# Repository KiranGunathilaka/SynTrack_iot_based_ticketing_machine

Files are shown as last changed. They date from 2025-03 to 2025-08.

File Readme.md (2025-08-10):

# Syntrack System

[Proposal](Readme_assets/Syntech-IoT_proposal.pdf)

[1st presentation](Readme_assets/First_Presentation.pdf)

[2nd presentation](Readme_assets/2nd_Presentation.pdf)

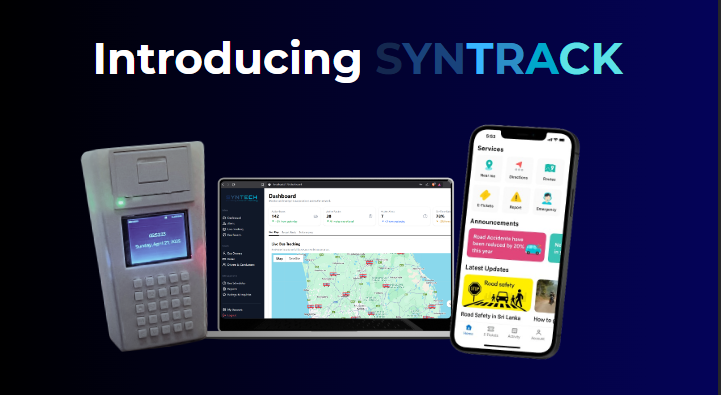
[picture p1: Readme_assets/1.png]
System

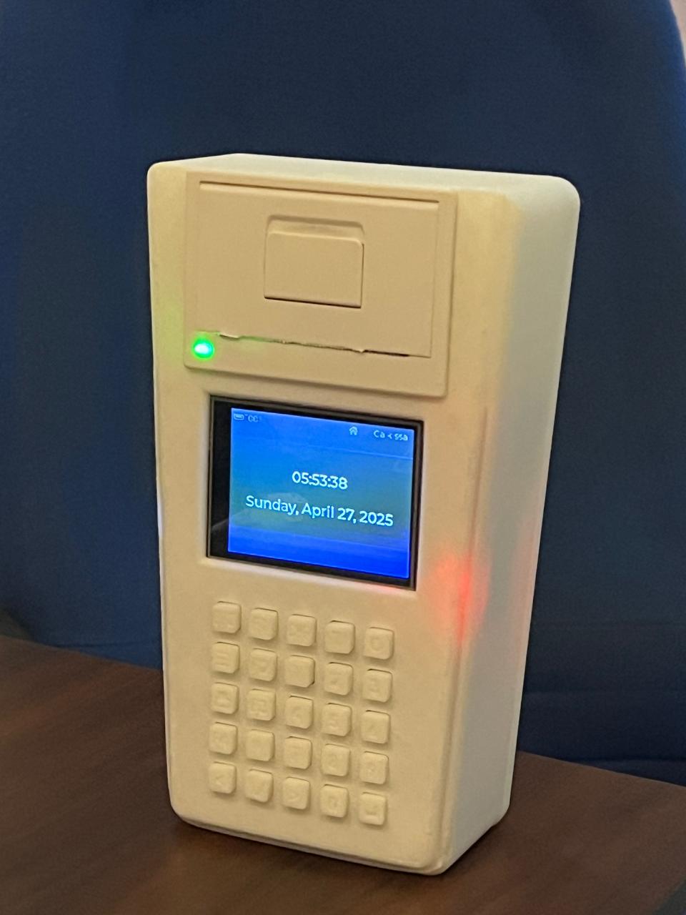
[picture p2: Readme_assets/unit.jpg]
Device

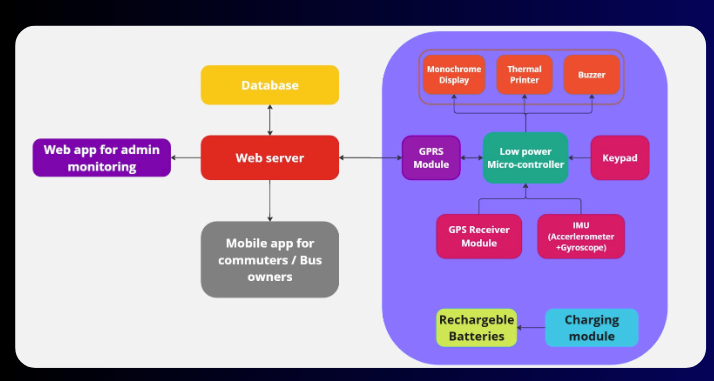
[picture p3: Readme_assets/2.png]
Brief Diagram

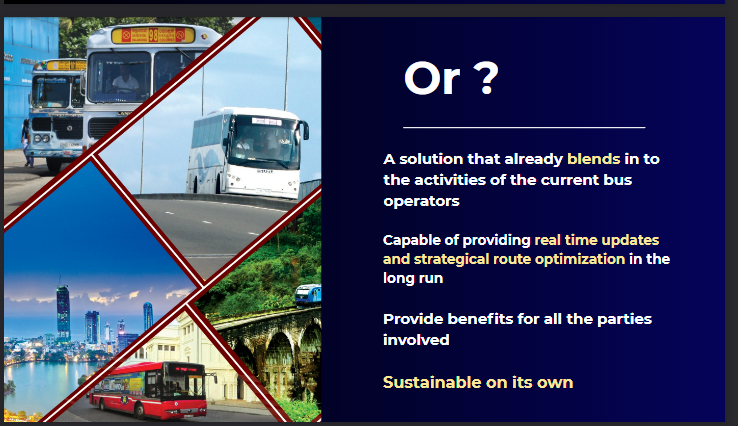
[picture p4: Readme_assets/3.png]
Why?


Enclosure V1
Enclosure V2

<div style="font-family: system-ui, -apple-system, Segoe UI, Roboto, Arial, sans-serif; line-height:1.4;">
  <h2 style="margin:0 0 8px;">Schematic Design</h2>
  <div style="display:grid; grid-template-columns:repeat(auto-fit, minmax(220px,1fr)); gap:12px; margin-bottom:20px;">
    <a href="https://res.cloudinary.com/dxavadkl2/image/upload/v1754797902/Job1_page-0001_mwngek.jpg" target="_blank" rel="noopener">
      Schematic Design — Page 1
    </a>
    <a href="https://res.cloudinary.com/dxavadkl2/image/upload/v1754797902/Job1_page-0002_kv0zv4.jpg" target="_blank" rel="noopener">
      Schematic Design — Page 2
    </a>
    <a href="https://res.cloudinary.com/dxavadkl2/image/upload/v1754797902/Job1_page-0003_uoopd7.jpg" target="_blank" rel="noopener">
      Schematic Design — Page 3
    </a>
    <a href="https://res.cloudinary.com/dxavadkl2/image/upload/v1754797902/Job1_page-0004_pi1ovk.jpg" target="_blank" rel="noopener">
      Schematic Design — Page 4
    </a>
    <a href="https://res.cloudinary.com/dxavadkl2/image/upload/v1754797902/Job1_page-0005_osse2e.jpg" target="_blank" rel="noopener">
      Schematic Design — Page 5
    </a>
    <a href="https://res.cloudinary.com/dxavadkl2/image/upload/v1754797902/Job1_page-0006_uicuav.jpg" target="_blank" rel="noopener">
      Schematic Design — Page 6
    </a>
    <a href="https://res.cloudinary.com/dxavadkl2/image/upload/v1754797901/Job1_page-0007_g4s4ae.jpg" target="_blank" rel="noopener">
      Schematic Design — Page 7
    </a>
    <a href="https://res.cloudinary.com/dxavadkl2/image/upload/v1754797901/Job1_page-0008_mnyr2u.jpg" target="_blank" rel="noopener">
      Schematic Design — Page 8
    </a>
    <a href="https://res.cloudinary.com/dxavadkl2/image/upload/v1754797901/Job1_page-0009_vxmq06.jpg" target="_blank" rel="noopener">
      Schematic Design — Page 9
    </a>
    <a href="https://res.cloudinary.com/dxavadkl2/image/upload/v1754797901/Job1_page-0010_rjnhxx.jpg" target="_blank" rel="noopener">
      Schematic Design — Page 10
    </a>
    <a href="https://res.cloudinary.com/dxavadkl2/image/upload/v1754797901/Job1_page-0011_hrwrx5.jpg" target="_blank" rel="noopener">
      Schematic Design — Page 11
    </a>
  </div>

  <h2 style="margin:0 0 8px;">PCB 2D (Routing)</h2>
  <div style="display:grid; grid-template-columns:repeat(auto-fit, minmax(220px,1fr)); gap:12px; margin-bottom:20px;">
    <a href="https://res.cloudinary.com/dxavadkl2/image/upload/v1754686981/Screenshot_2025-08-09_013852_g663fi.png" target="_blank" rel="noopener">
      PCB 2D Routing — View 1
    </a>
    <a href="https://res.cloudinary.com/dxavadkl2/image/upload/v1754686981/Screenshot_2025-08-09_013907_rphc70.png" target="_blank" rel="noopener">
      PCB 2D Routing — View 2
    </a>
    <a href="https://res.cloudinary.com/dxavadkl2/image/upload/v1754686980/Screenshot_2025-08-09_013914_csmo0g.png" target="_blank" rel="noopener">
      PCB 2D Routing — View 3
    </a>
    <a href="https://res.cloudinary.com/dxavadkl2/image/upload/v1754686980/Screenshot_2025-08-09_013922_lapydj.png" target="_blank" rel="noopener">
      PCB 2D Routing — View 4
    </a>
  </div>

  <h2 style="margin:0 0 8px;">3D View</h2>
  <div style="display:grid; grid-template-columns:repeat(auto-fit, minmax(220px,1fr)); gap:12px; margin-bottom:20px;">
    <a href="https://res.cloudinary.com/dxavadkl2/image/upload/v1754686980/Screenshot_2025-08-09_014124_jlmipr.png" target="_blank" rel="noopener">
      3D View — Image 1
    </a>
    <a href="https://res.cloudinary.com/dxavadkl2/image/upload/v1754686980/Screenshot_2025-08-09_014212_eycq3m.png" target="_blank" rel="noopener">
      3D View — Image 2
    </a>
  </div>

  <div style="margin-top:10px; padding:12px; background:#f9fafb; border:1px solid #eee; border-radius:8px;">
    <p style="margin:0 0 6px;"><strong>Notes</strong></p>
    <ul style="margin:0 0 0 18px;">
      <li>All layers are ground-poured except the layer above the bottom layer, which is the 3.3&nbsp;V plane.</li>
      <li>Design isn’t fully complete. Midway through, due to time and budget constraints, the PCB was deprioritized. Placement and routing aren’t fully optimized; this was completed as a learning exercise to make use of the time already invested.</li>
    </ul>
  </div>
</div>

[Some collabarative files are here too](https://github.com/KavishkaJayakody/SLIoT_Syntec)

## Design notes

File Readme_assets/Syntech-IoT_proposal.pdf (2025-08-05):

# IoT-enabled Bus Ticketing Device Project Proposal

Team Name | Syntech-IoT
Category | University Category

# 1) Problem Definition

## 1.1) Introduction

Sri Lanka’s public bus system is essential for daily commutes but faces persistent challenges such as overcrowding, unreliable schedules, financial mismanagement, and safety concerns. These issues result in commuter discomfort, wasted time, and financial losses for bus operators. The primary cause is the lack of real-time information on bus occupancy, location, and arrival times, forcing operators to rely on inefficient fixed schedules due to limited data on ridership patterns.

Additionally, poor compliance with speed limits and route adherence compromises safety and reliability, often going unchecked due to inadequate monitoring.

To address these challenges, our team proposes an IoT-enabled ticketing machine that not only streamlines ticketing but also collects real-time operational data. Since ticketing machines are already a mandatory requirement in the public transport sector, integrating IoT functionality into them is a more efficient and cost-effective approach than deploying a separate monitoring system.

This solution will benefit commuters, operators, bus owners, and regulators by improving efficiency, comfort, safety, and decision-making. Moreover, while existing ticketing machines are priced above Rs. 35,000, our product offers these advanced features at a significantly lower cost, making it an affordable and effective solution for transport management and network monitoring.

## 1.2) Problem Analysis

It is very evident that the Sri Lanka’s public bus system have become inefficient and unreliable according to public opinion and first-hand experiences, leading to several challenges:
- Time Wastage: Unreliable schedules force passengers to wait long periods without knowing when a bus will arrive.

- Inefficient Route Mapping: Uneven bus distribution causes overcrowding on some routes and underutilization on others.
- Limited Night-time Service: Few buses operate at night, leaving passengers stranded.
- Lack of Accountability: No mechanism exists for passengers to report misconduct or poor service.
- Unsafe Rides: Reckless driving and poor safety enforcement create hazardous travel conditions.
- Route Uncertainty: No reliable system exists to guide commuters, tourists on the best routes to their destination, bus stops for the routes in non-urban areas.
- Cash Payment Issues: Dependence on cash leads to overpaying or difficulties in finding exact change and there’s no transparency between the operators, owners and the authorities.
- Environmental Impact: Paper tickets contribute to litter and waste; an e-ticketing system can reduce this burden.

Our solution wishes to address each of this issues by utilizing our IoT device and its software counterpart.

# 2)Proposed Solution

## 2.1) Proposed Product

IoT-enabled Ticket Issuing Machine with mobile transit app
Our device enhances Sri Lanka's public bus network by tracking real-time data and improving efficiency.
Key Features:
- Tracks bus location, occupancy, and speed in real-time.
- Transmits data to a central system for analysis and optimization.
- Display the route data and collect feedback through a mobile application.

Breakdown
1. Real-Time Data Tracking
- Location Tracking: GPS provides live bus locations via ticket issuing machine.
- Speed Monitoring: Detects speeding; sends alerts for safety.
- Route Adherence: Ensures compliance with predefined routes.
2. Ticket Issuing with IoT Integration
- Passenger Count: Monitors number of tickets issued.
- Occupancy Monitoring: Prevents overcrowding with real-time capacity updates.
- Payment Options: Supports cash, contactless, and digital payments.

3. Centralized System & Analysis
- Collects and securely transmits data (location, speed, occupancy).
- Uses AI/ML to identify patterns for route optimization and demand management.
4. Stakeholder Benefits
- Commuters: Access live bus updates via an app to reduce waiting times.
- Operators: Optimize scheduling and identify inefficiencies.
- Authorities: Enforce safety, improve planning, and manage routes better.
5. Notifications and Alerts
- Commuters: Get updates on arrivals, seat availability, and delays.
- Operators/Regulators : Receive alerts for overcrowding, speeding, and route deviations.
6. Future Scalability
- Expansion: Begin with pilot routes and scale to the full network.
- Integration: Potential to connect with smart city systems and traffic management.

## 2.2) Uniqueness of the Solution

1. Upgrade to Existing System
Enhances traditional handheld ticketing machines simplifying adoption by leveraging familiar tools, making implementation easier compared to entirely new systems.
2. Real-Time Speed and Safety Monitoring
Combines GPS and speed tracking to detect reckless driving, proactively ensuring passenger safety and addressing Sri Lanka’s road conditions.
3. Passenger Feedback System
Empowers passengers to report issues or commend service, promoting accountability and service improvements beyond just operational metrics.
4. Overloading Control with Ticket Monitoring
Integrates passenger limits and pre-booking to manage passenger capacity, directly addressing overloading and improving boarding efficiency.
5. Real-Time Bus Tracking for Passengers
Provides live bus locations and arrival times, a first for Sri Lanka's private and SLTB buses, enhancing trip planning, reliability, and convenience.
6. Data-Driven Insights
Collects actionable data for route optimization, road safety and policy planning, supporting both operational efficiency and long-term infrastructure improvements.

# 3)Technical Overview and Implementation

## 3.1) Technical Details

The | IoT-enabled
ticketing machine will be
employing a low-power micro-controller as it needs to operate for a maximum duration using battery power. It will utilize a keypad to take inputs from the conductor and outputs will be delivered to the monochrome LCD display, thermal printer and a buzzer as a usual
ticketing | machine. | Crowd

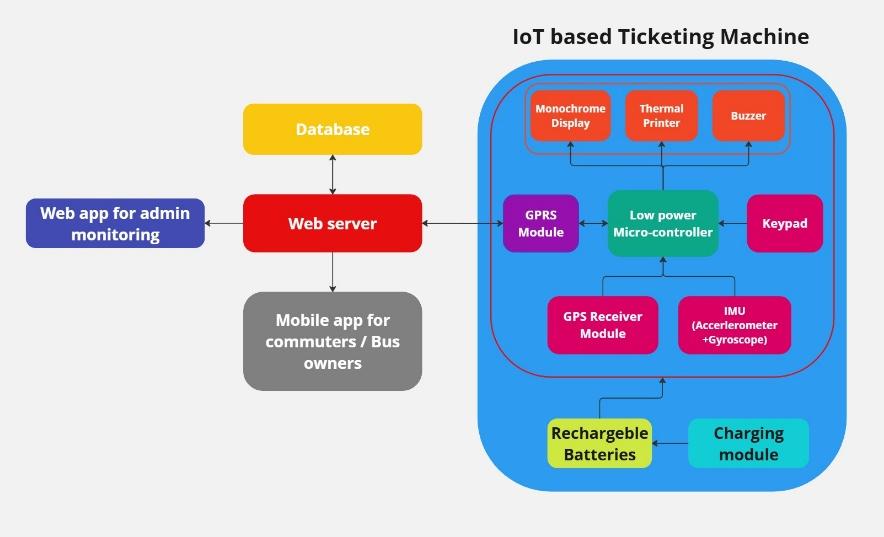
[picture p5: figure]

information will be recorded and reported to the server by tracking the issued tickets count and start and destination of the issued tickets. The GPRS (General Packet Radio Service) module will allow the device to access cellular networks using a SIM card thus enabling HTTP/IP communication between the webserver and device. The GPS receiver module will capture location/ velocity and time data from the GPS/GNSS networks, and captured data will be continuously delivered to the webserver. This data will be processed and displayed on the commuter mobile app and admin web app so that end users can see next arriving bus, estimated times, number of busses in the route, occupancy of the bus, and other additional features. Also drivers and conductors will able to see the number of waiting commuters through the device as the server and IoT device communication is bi-directional. The IMU sensor will be used to detect rapid acceleration/decelerations and that data will be processed along with location data real-time, in the server or on-device, using a pre-trained ML model, to identify irregular, unsafe driving patterns and crash incidents.

## 3.2) User Scenario

For conductors, the device will function as a standard ticketing machine, requiring no extra effort. For commuters, the app will notify when a bus is ready to depart from the depot, displaying its real-time location and estimated arrival times at stops. This allows users to adjust their schedules and minimize waiting times. Additionally, real-time occupancy data will help commuters decide whether to board the current bus, wait for the next, or take an alternate route. Commuters can also mark themselves as “waiting” for routes with flexible or night schedules. This lets drivers see the number of waiting passengers and adjust their routes slightly to improve convenience and safety.

# Team Details

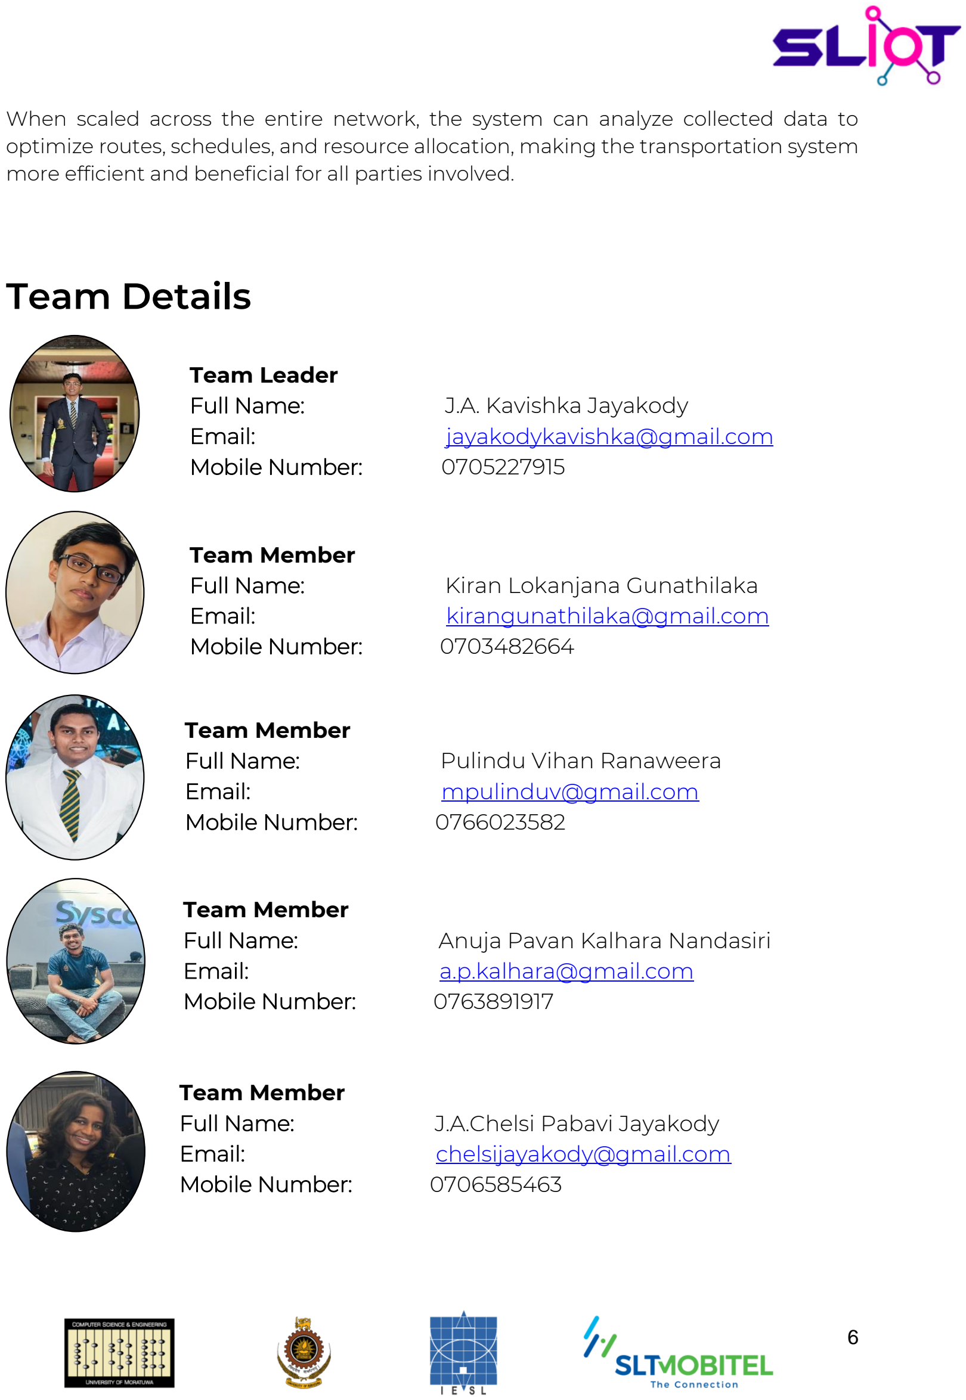
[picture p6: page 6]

When scaled across the entire network, the system can analyze collected data to optimize routes, schedules, and resource allocation, making the transportation system more efficient and beneficial for all parties involved.

Team Leader
Full Name: | J.A. Kavishka Jayakody
Email: | jayakodykavishka@gmail.com
Mobile Number: | 0705227915

Team Member
Full Name: | Kiran Lokanjana Gunathilaka
Email: | kirangunathilaka@gmail.com
Mobile Number: | 0703482664

Team Member
Full Name: | Anuja Pavan Kalhara Nandasiri
Email: | a.p.kalhara@gmail.com
Mobile Number: | 0763891917

Team Member
Full Name: | Pulindu Vihan Ranaweera
Email: | mpulinduv@gmail.com
Mobile Number: | 0766023582

Team Member
Full Name: | J.A.Chelsi Pabavi Jayakody
Email: | chelsijayakody@gmail.com
Mobile Number: | 0706585463

# 4) Additional Information

For the system to be successfully implemented and deliver its full benefits, it must be deployed across all buses within at least one urban area. Additionally, to ensure the system’s effectiveness, all commuters must be required by law to obtain tickets.

To accommodate all demographics, the e-ticketing system should be introduced alongside traditional paper tickets, as some passengers may lack the technological literacy to adopt digital payments immediately. Furthermore, while e-ticketing is a crucial enhancement, it may not be included in the Minimum Viable Product (MVP) and can be introduced as a future extension based on the system’s success.

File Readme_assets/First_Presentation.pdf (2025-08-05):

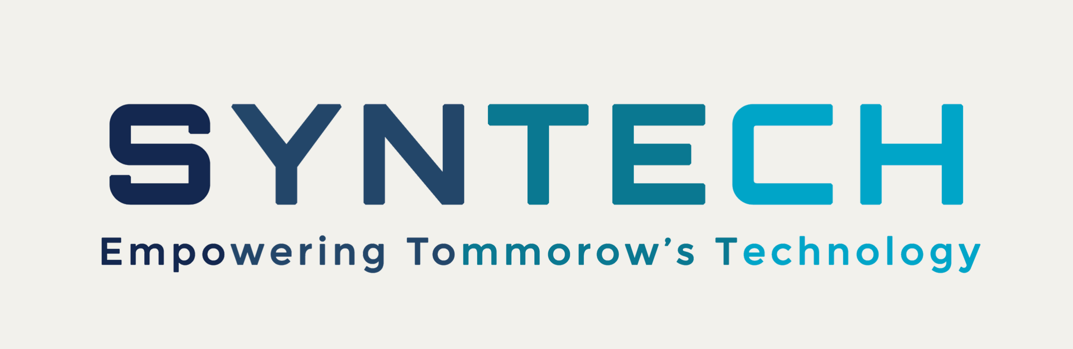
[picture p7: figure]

# Are you satisfied with the current bus transportation?

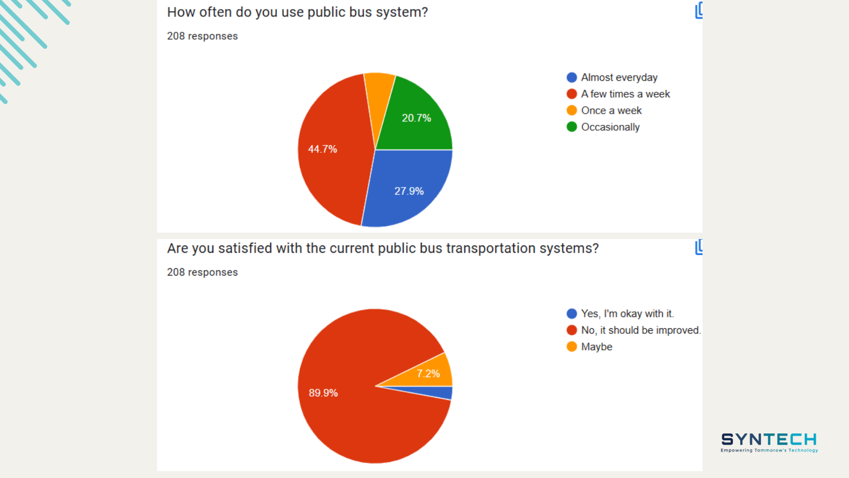
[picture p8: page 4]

# Problem Statement

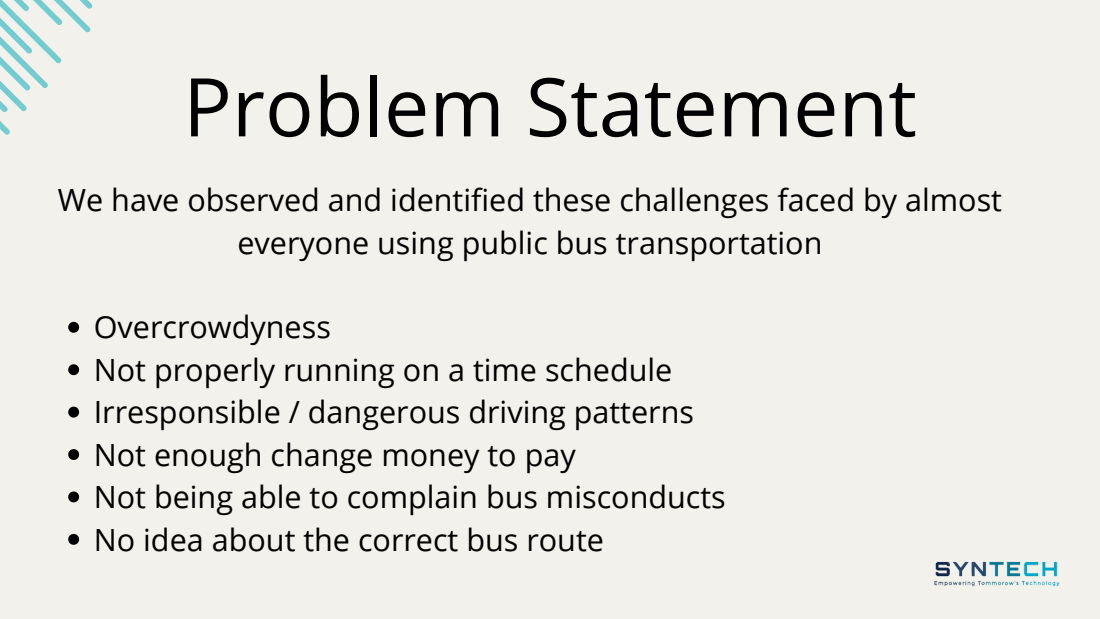
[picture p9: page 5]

We have observed and identified these challenges faced by almost

everyone using public bus transportation

Overcrowdyness
Not properly running on a time schedule
Irresponsible / dangerous driving patterns
Not enough change money to pay
Not being able to complain bus misconducts
No idea about the correct bus route

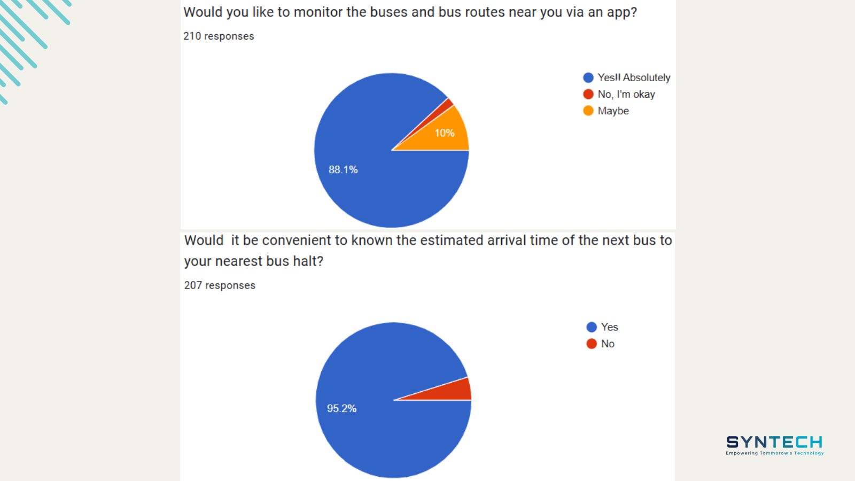
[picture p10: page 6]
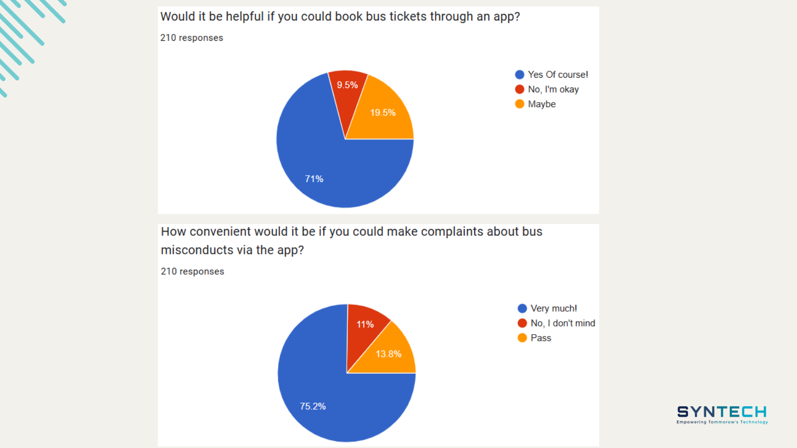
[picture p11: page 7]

# What Can We Do

A fixed GPS tracker attached to the bus. A community based data collection system

To Regulate And Monitor Busses

Intergrate a GPS tracker and a bus data monitoring unit to get insights Using legal officers to monitor busses constantly

# An IoT Enabled Ticketing Machine

A ticketing machine similar to the existing bus ticketing machine Intergrated GPS tracker
Real time motion detection Passesnger count feed

# IoT enabled Bus Ticketing Device

# Device Features

Our Device act as a ordinary bus ticketing machine from the bus conductors end but with IoT capabilities

TFT LCD display with 5 x 5 scanning Keyboard

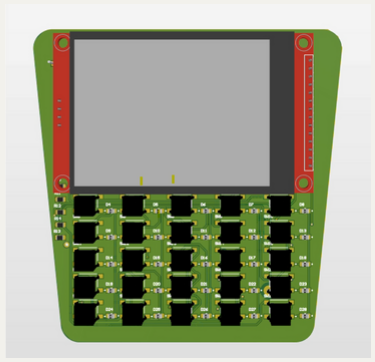
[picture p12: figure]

58mm Thermal Printer

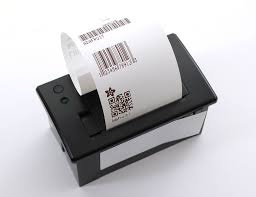
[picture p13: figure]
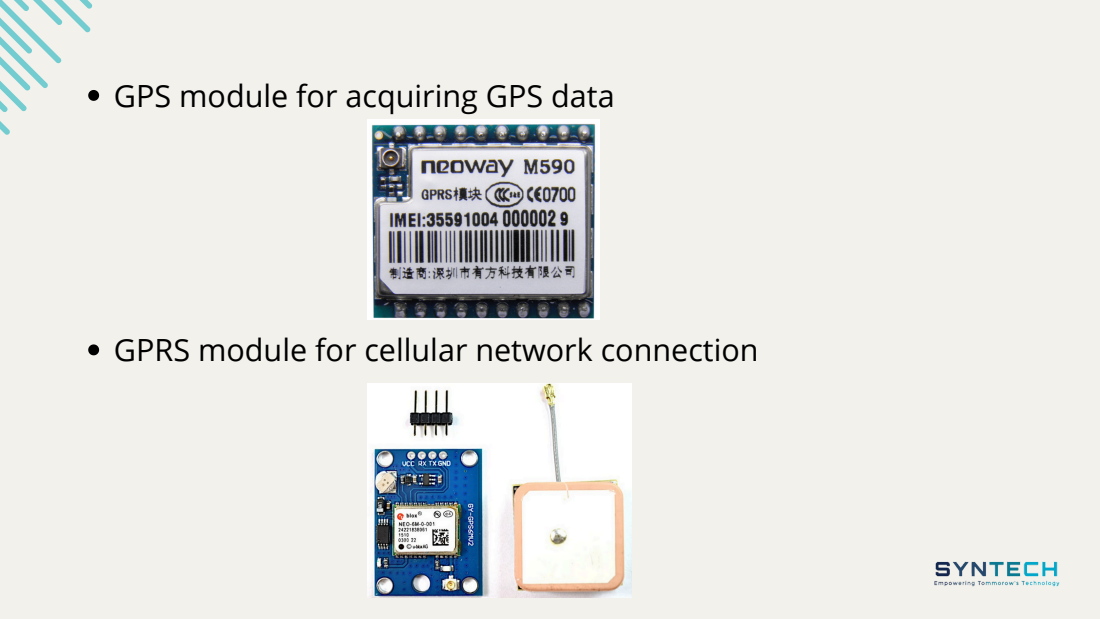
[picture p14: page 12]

GPS module for acquiring GPS data

GPRS module for cellular network connection

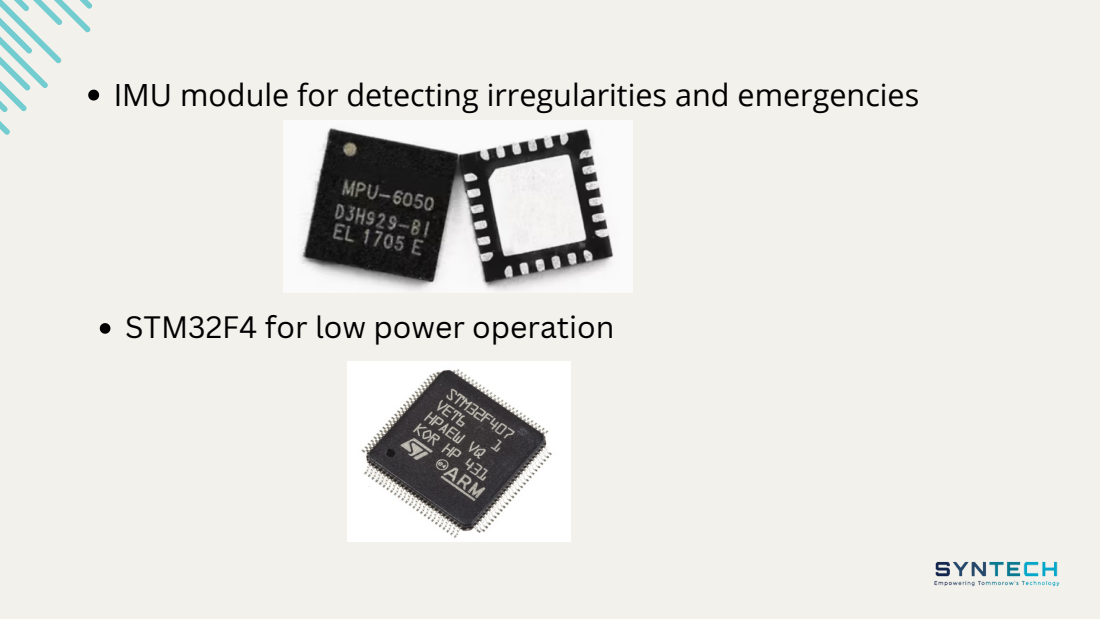
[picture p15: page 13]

IMU module for detecting irregularities and emergencies

STM32F4 for low power operation

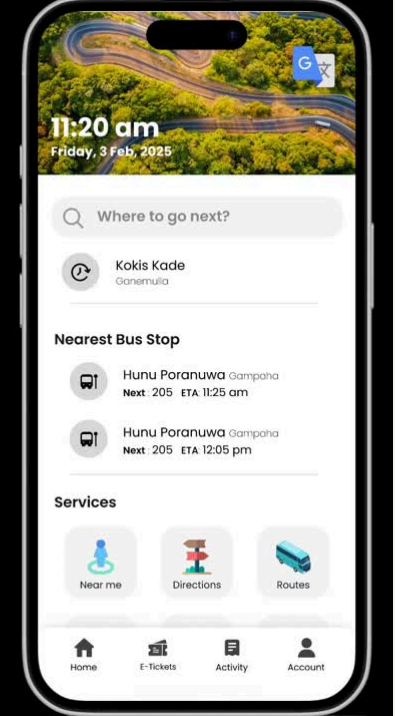
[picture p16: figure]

# SYNTRACK

## Commuter App

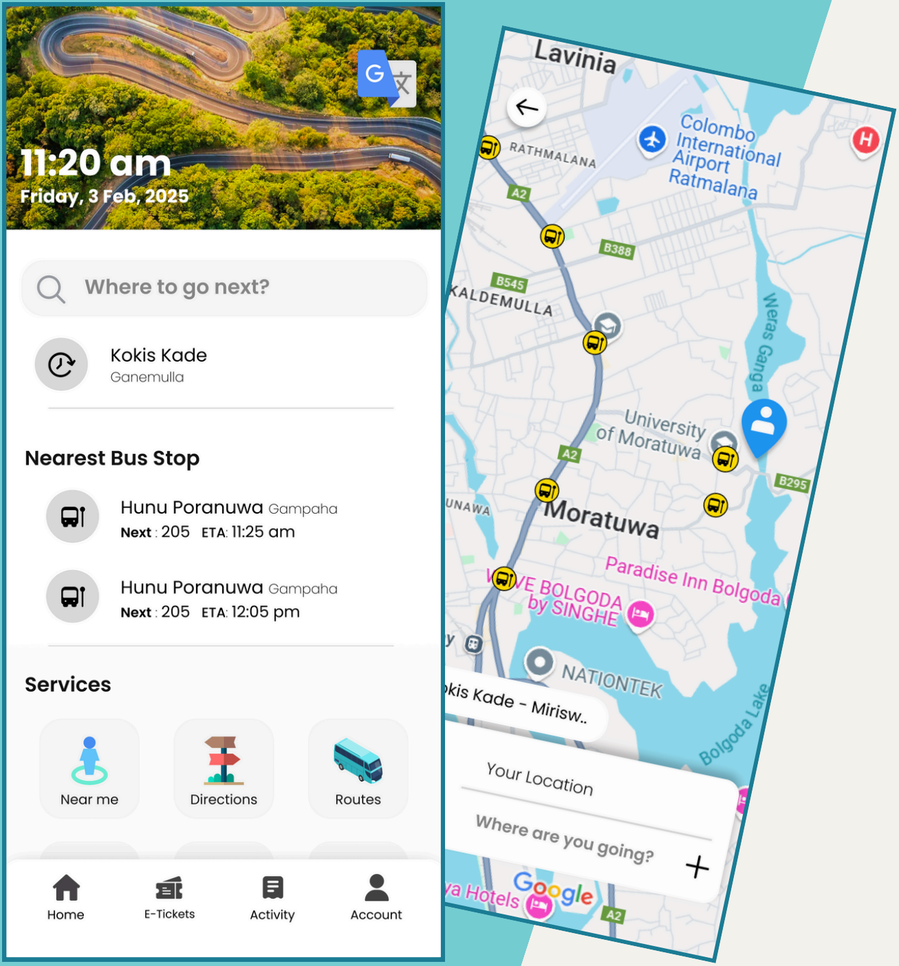
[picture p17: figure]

# DESIGN

Familiar Designs
Accessibility

## IMPLEMENTATION

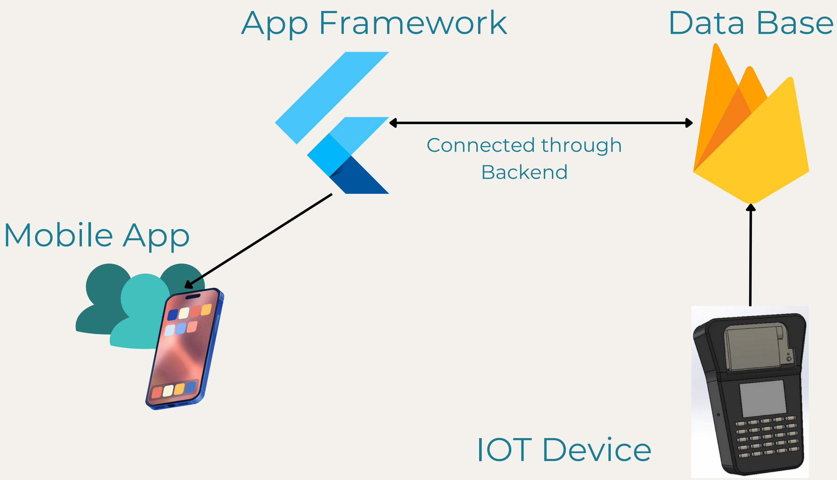
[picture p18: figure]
App Framework; Data Base; IOT Device; Mobile App; Connected through Backend

## Real Time Bus Tracking

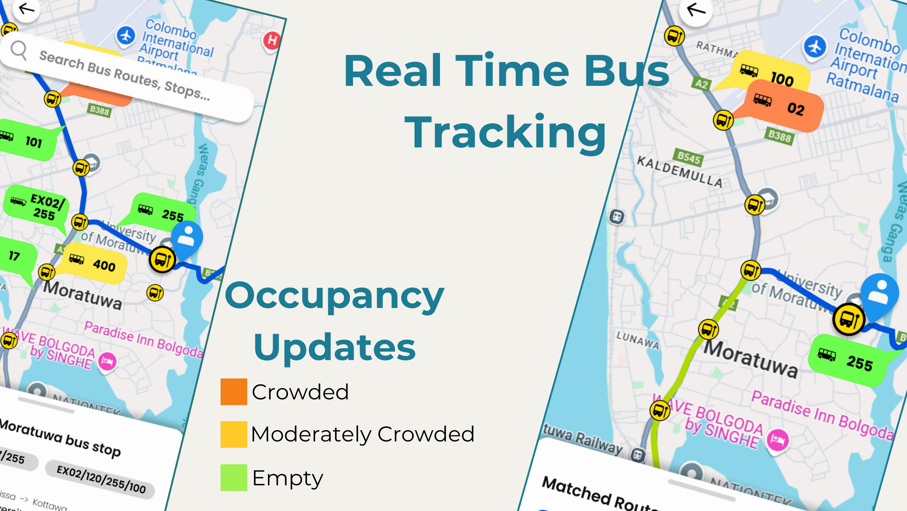
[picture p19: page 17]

## Occupancy Updates

Crowded
Moderately Crowded
Empty

## Commuter Support

## Route Info

Ticketing | Notifications

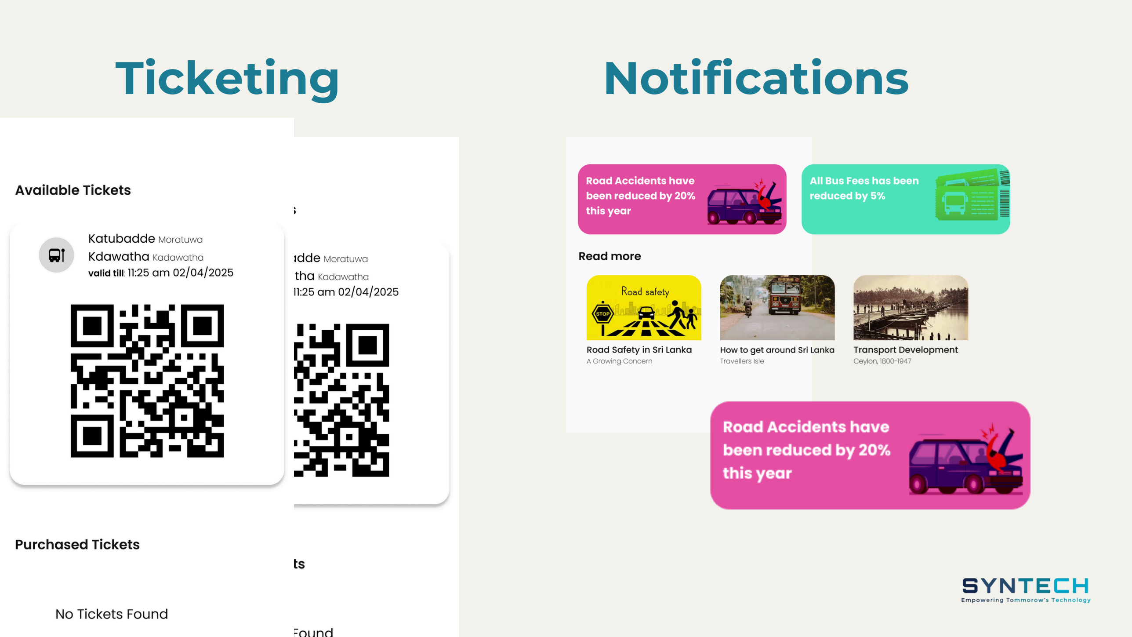
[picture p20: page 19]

# SYNTRACK

## Commuter App

Smoother Safer Predictable

# Web Platform

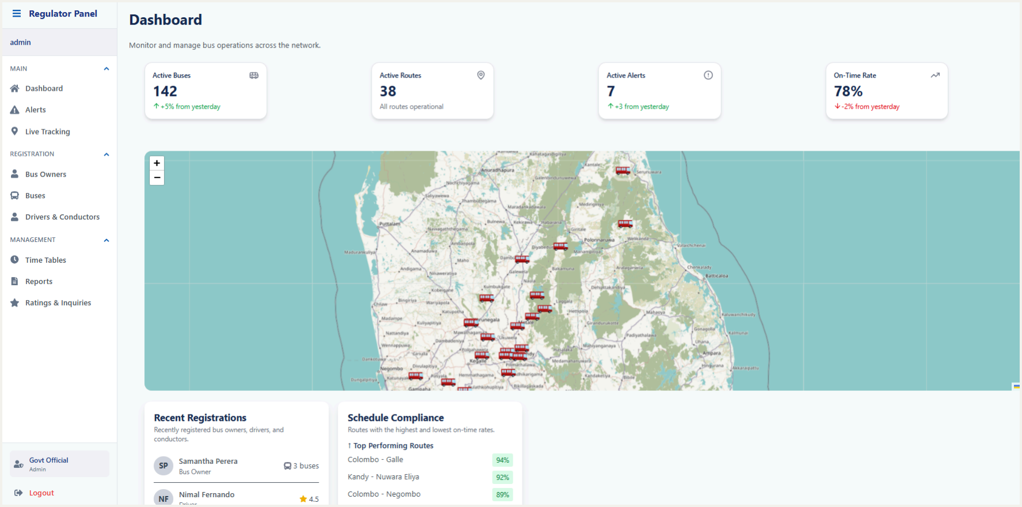
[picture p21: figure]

# Web Platform

## Live-tracking of all the busses in the network

## Bus owner and operator registration

## Automated alerts for irresponsible and dangerous driving behavior

## Quarterly report generation featuring optimized resource allocation recommendations based on analyzed

commuter pattern data.

# Future Development

## Adaptive resource allocation for routes using collected commuter patterns

## Aiming for smart city concepts that aligns with Sustainable Development Goals (SDG 17)

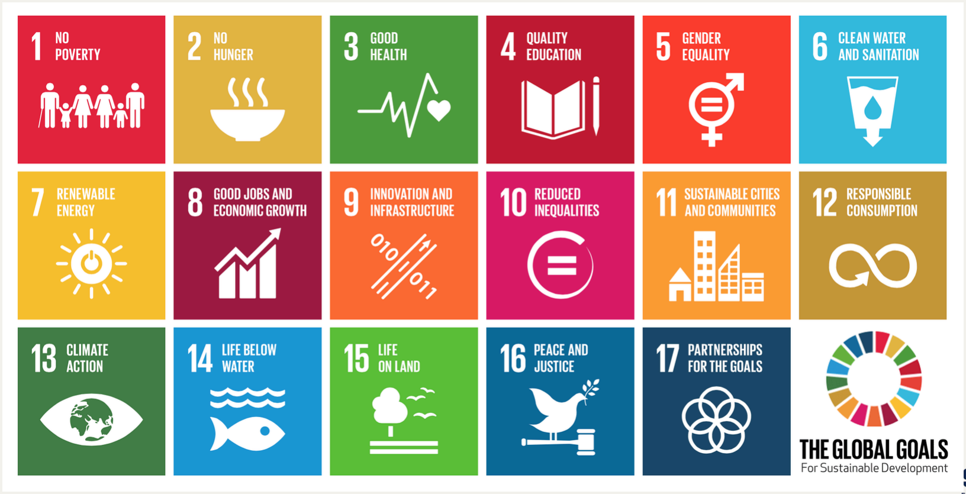
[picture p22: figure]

## Integrate multiple transportation modes and collaborate with service providers to

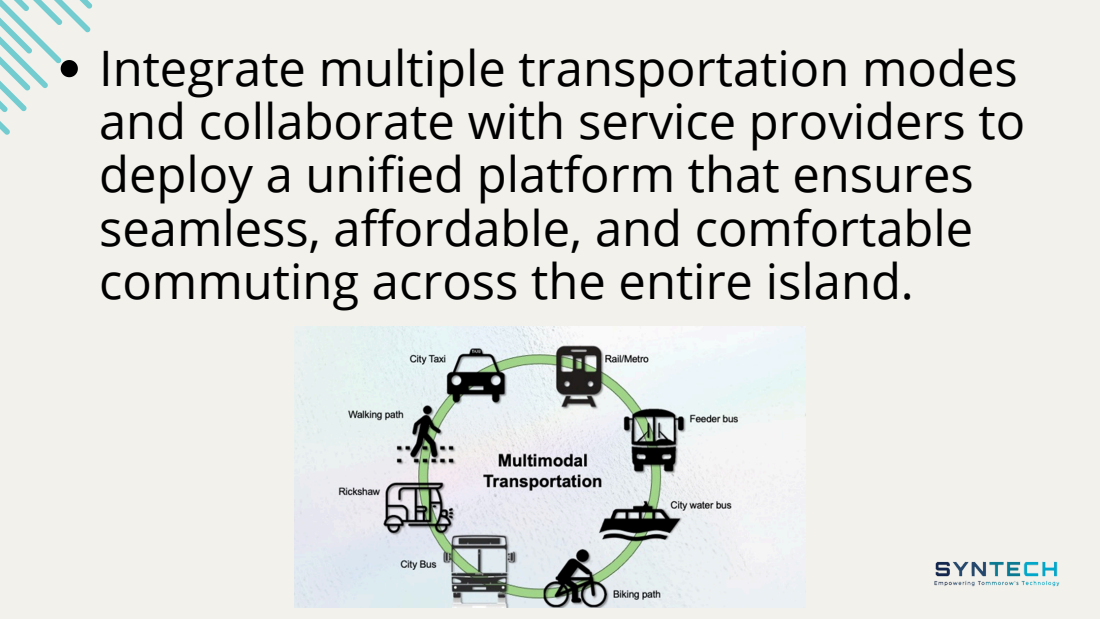
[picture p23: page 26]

deploy a unified platform that ensures
seamless, affordable, and comfortable
commuting across the entire island.

# Our progress

### Ticketing device

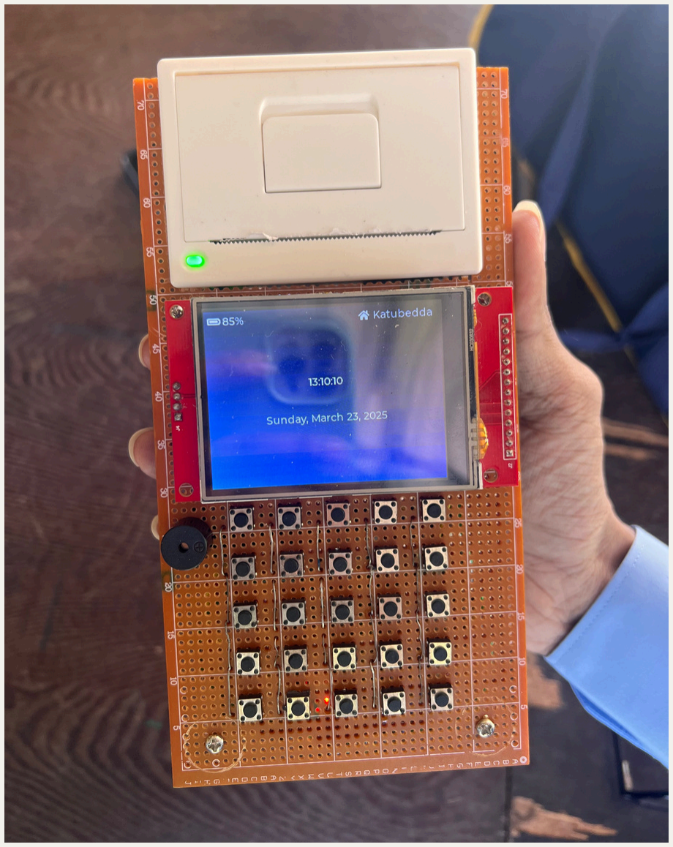
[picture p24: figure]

### Commuter app

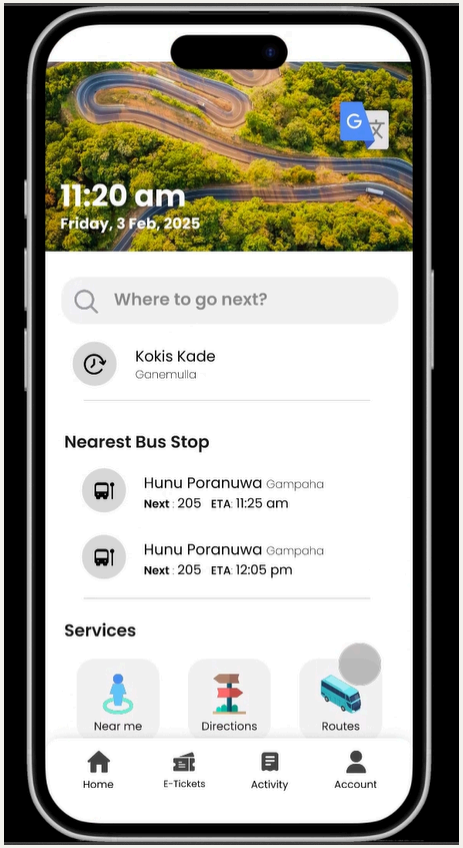
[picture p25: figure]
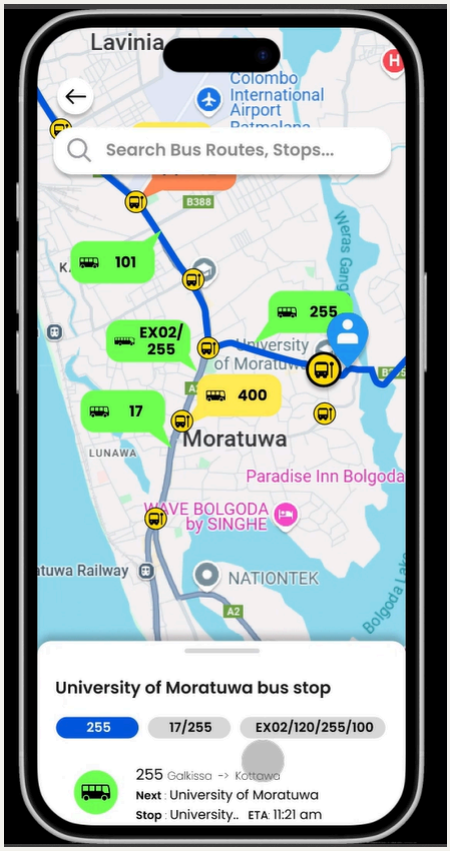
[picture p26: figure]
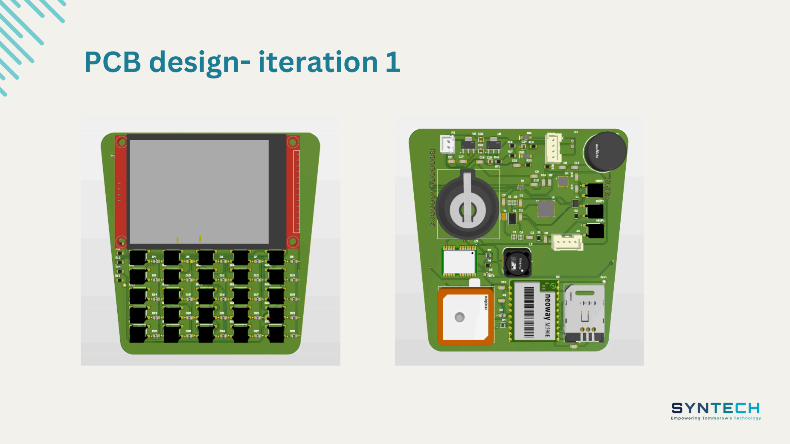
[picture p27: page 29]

### PCB design- iteration 1

### Web portal

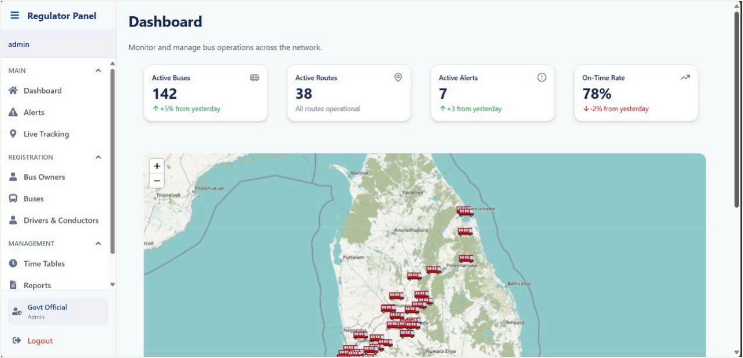
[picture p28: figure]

# Why This System Can Succeed

# Strengths, Challenges & Opportunities

Strengths 40%; Opportunities 30%; Weaknesses 20%; Threats 10%

# Demand & Feasibility


Over 60% of public transport users struggle with inefficiency & fraud.

Ministry of Transport, Highways, Ports and Civil Aviation

GPS tracking is a must → Countries like India, Singapore, and the UK have already implemented similar systems.
Sri Lanka has over 70% smartphone penetration

Expanding 4G & 5G networks
Sri Lanka’s push for digital transformation & smart city projects supports this initiative.

## Business Plan & Revenue Model

Government doesn’t need to keep funding this. It’s self sustaining.

Digital Ticketing Fees → A small service fee per ticket . Advertising Revenue → Sell ad space on bus stops, ticketing machines, and the app.
Data Monetization → Transport analytics for private companies

No. Buses

Time period

Additional

Phase 1 | Phase 2 | Phase 3

## How We Make This Happen

500 buses in Colombo | Scale to 3,000+ intercity buses. | Island - Wide Execution
First 6 months | 6 - 18 months | 18+ Months

Passenger app + real-time tracking system goes live.
Introduce AI-driven route
optimization.

International partnerships &
licensing opportunities.

## How We Mitigate Risks

Resistance from Private Bus Owners ? - Bring new rules and regulations
High Initial Costs? - Staggered investment plan + revenue generation starts early.
Passenger Adoption? - Public awareness campaigns + incentives for digital payments.

# Thank You!

# We are

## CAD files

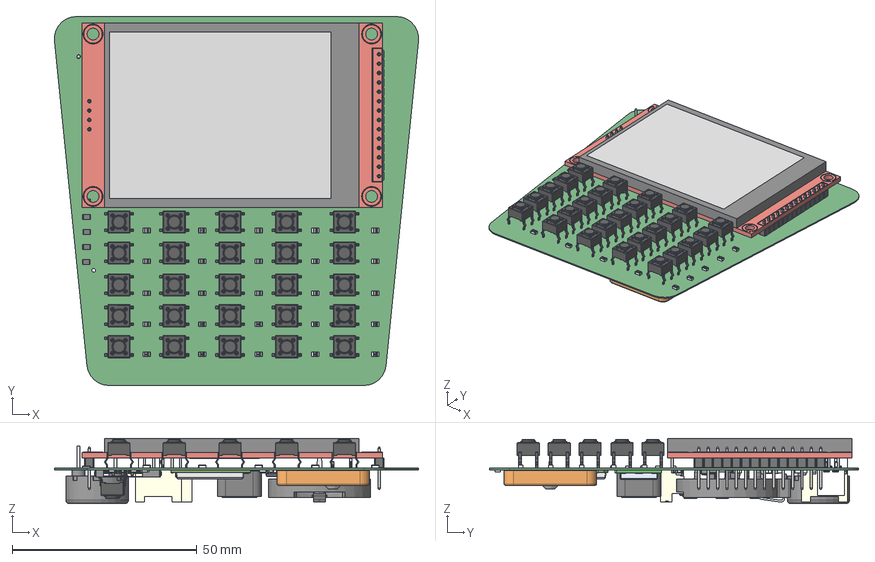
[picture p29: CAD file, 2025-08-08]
PCBs/SynTrack/Main.step
98.7 x 100.0 x 17.7 mm
plastic x 2
pins x 4
terminal
top x 3
logo x 6
Package
Leads
LID
Logo
Switch_C&K_PTS645SM43SMTR92LFS_eec x 28
Notch 2 x 2
Extruded x 67
M590 Neoway
Mid_Body x 14
Mark x 14
part number x 2
terminals x 5
base
Leadframe x 2
Core
ShieldRing
Glue
Vishay logo
1x1_Pin_Header_2.54mm x 18
Molex
notch
Diode_Taiwan_Semiconductor_TS4148_RYG_eec x 162
Cap_KEMET_C0805C472J3HAC_eec x 12
Keystone_Logo
Molex Logo

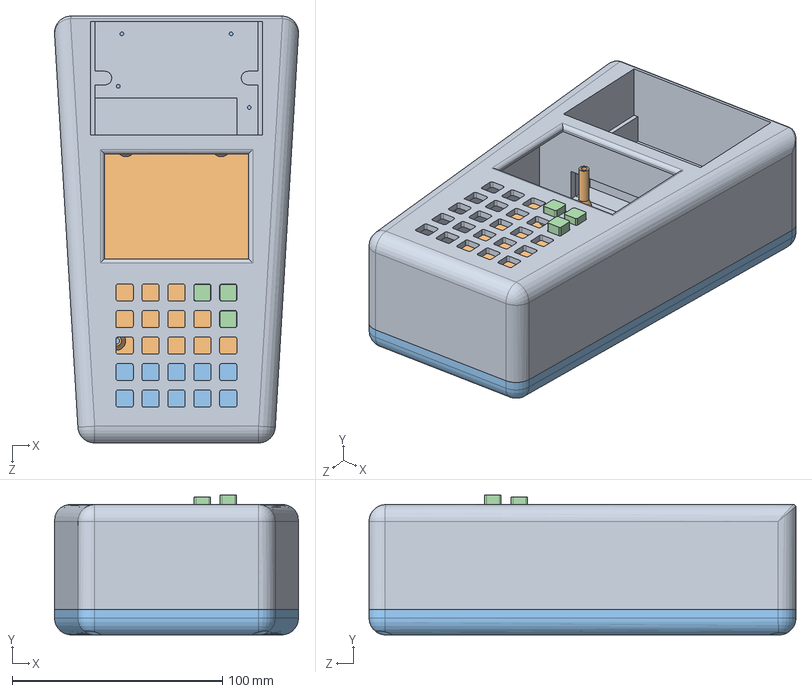
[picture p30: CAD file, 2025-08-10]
Enclosure/Enclosure2/Enclosure/Assem1.SLDASM
116.0 x 66.5 x 203.0 mm
enclsoure2
MidSurface
BackCover
Button x 3

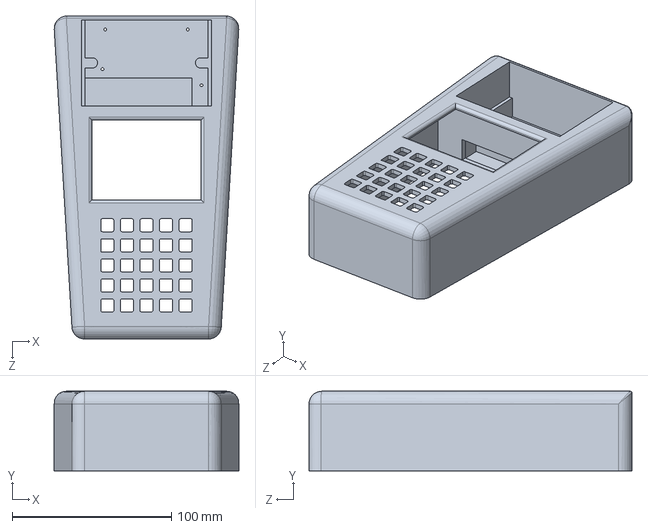
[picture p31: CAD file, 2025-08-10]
Enclosure/Enclosure2/Enclosure/enclsoure2.SLDPRT
116.0 x 50.0 x 203.0 mm

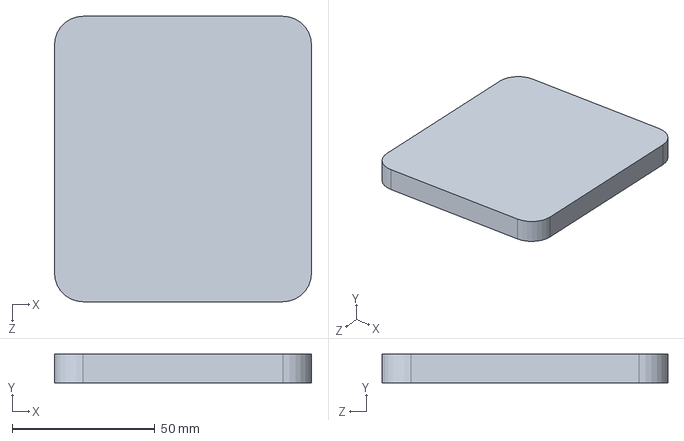
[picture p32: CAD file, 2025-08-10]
Enclosure/Enclosure2/PCB/Part1.SLDPRT
90.0 x 10.0 x 100.0 mm

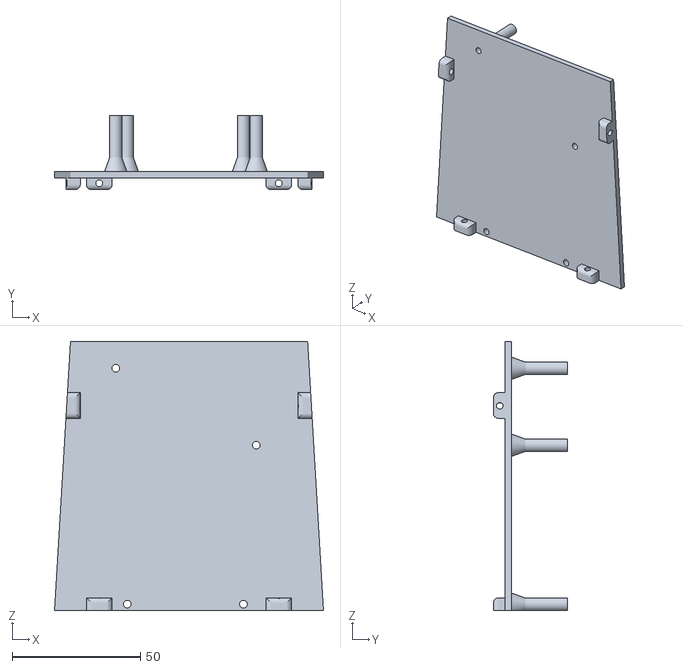
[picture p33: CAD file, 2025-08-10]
Enclosure/Enclosure2/STL/MidSurface.STL
104.9 x 29.0 x 105.0

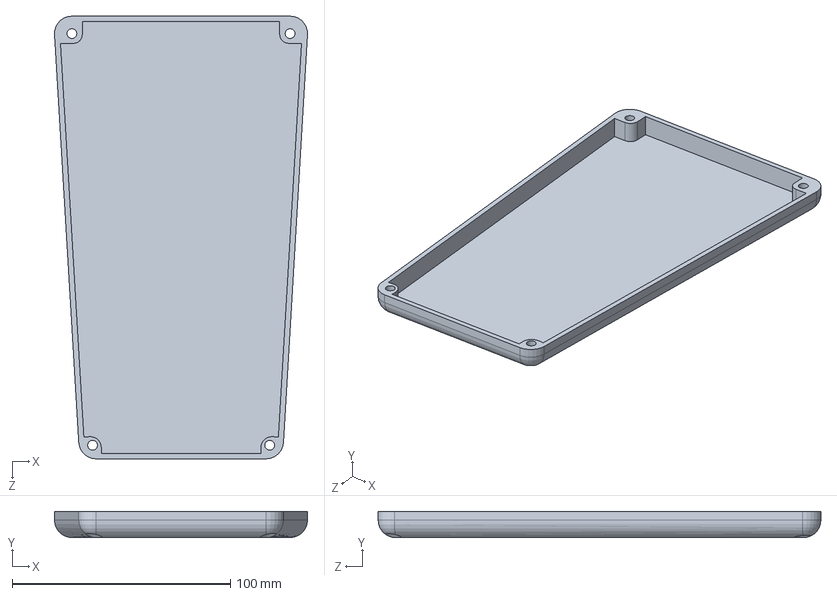
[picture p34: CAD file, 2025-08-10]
Enclosure/Enclosure2/Enclosure/BackCover.SLDPRT
116.0 x 12.0 x 203.0 mm

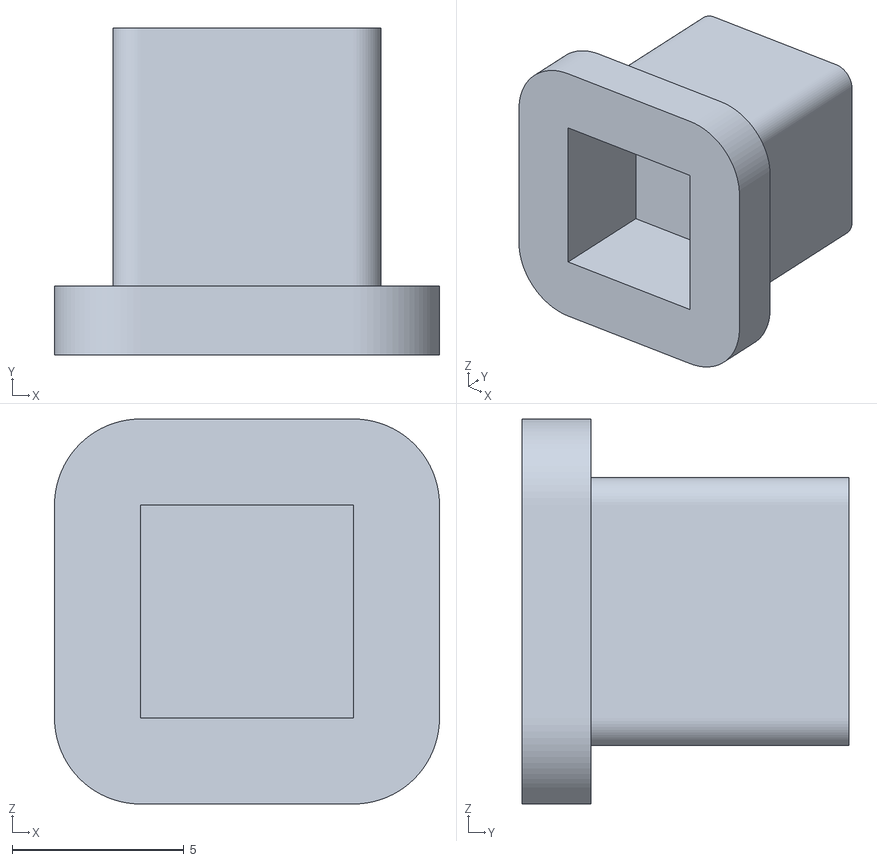
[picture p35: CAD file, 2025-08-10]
Enclosure/Enclosure2/STL/Button.STL
11.2 x 9.50 x 11.2

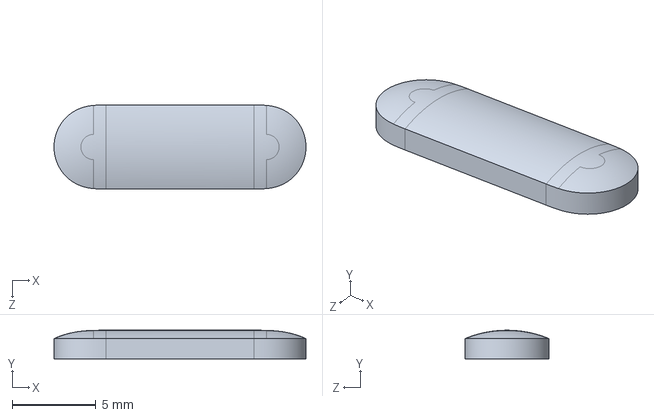
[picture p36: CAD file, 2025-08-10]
Enclosure/Enclosure1/lozengeButton.SLDPRT
15.0 x 1.70 x 5.00 mm

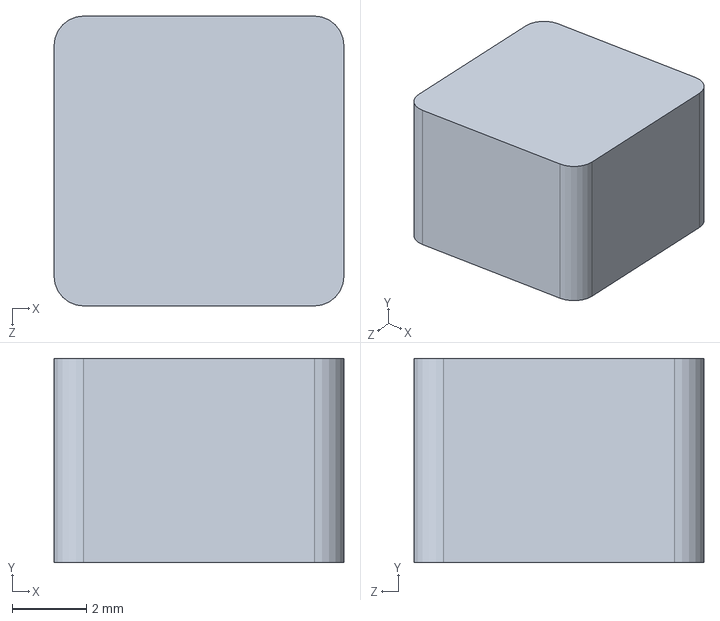
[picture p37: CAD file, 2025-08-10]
Enclosure/Enclosure2/Enclosure/button2.SLDPRT
7.80 x 5.50 x 7.80 mm

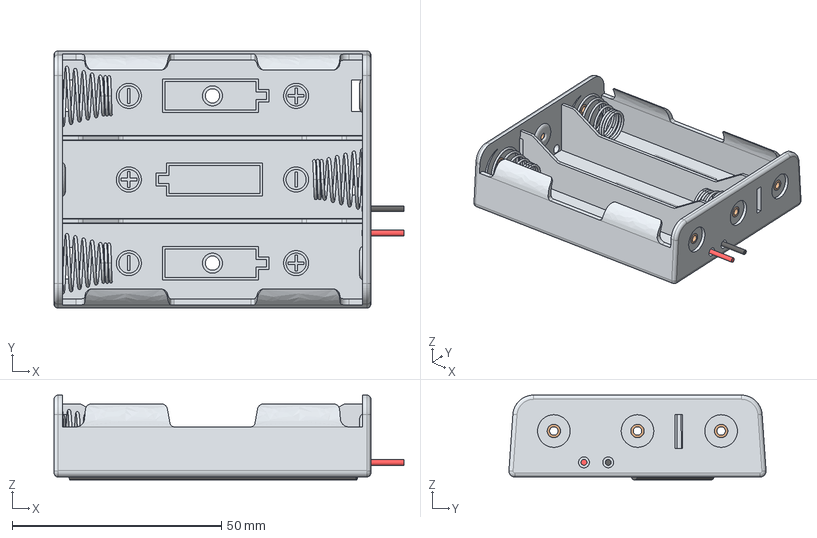
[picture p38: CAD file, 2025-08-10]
Enclosure/Enclosure1/batteryCase18650x3.step
83.7 x 61.5 x 20.3 mm
Corps
FilNoirUnder001
Positif1
Spring1
Spring3
rivet x 6
Positif2
Positif3
FilRouge
FilNoir
FilNoirUnder

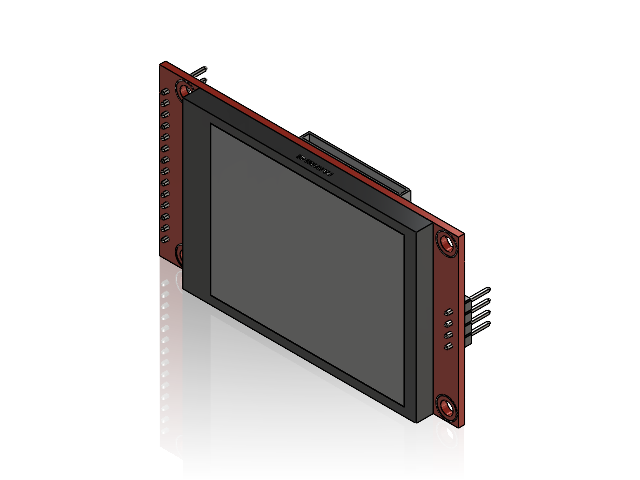
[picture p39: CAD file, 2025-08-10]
Enclosure/Enclosure1/TFT LCD 2.4 inch ILI9341.step.SLDASM
1x1_Pin_Header_2.54mm.step x 4
1x1_Pin_Header_2.54mm_1.step x 14
Component1.step
Component2.step
TFT LCD 2.4 inch ILI9341.step
TFT LCD 2.4 inch ILI9341-0.step
TFT LCD 2.4 inch ILI9341-1.step
TFT LCD 2.4 inch ILI9341-2.step
TFT LCD 2.4 inch ILI9341-3.step
TFT LCD 2.4 inch ILI9341-4.step
TFT LCD 2.4 inch ILI9341-5.step

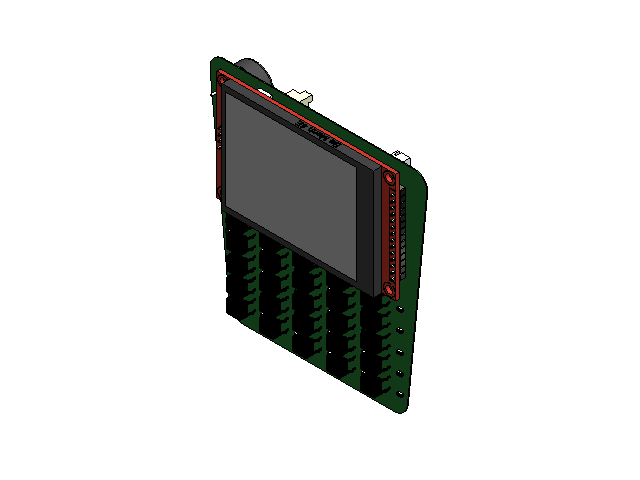
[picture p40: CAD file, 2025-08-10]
Enclosure/Enclosure1/MainPCB.SLDASM
plastic.step x 2
pins.step x 2
body.step
terminal.step
top.step
Logo.step
Package.step
Leads.step
LID.step
Logo_1.step
Switch_C&K_PTS645SM43SMTR92LFS_eec.step x 28
1.step x 2
Notch 2.step x 2
Extruded.step
6324664208.step
M590 Neoway.step
Extruded-0.step
Mid_Body.step x 6
Mark.step x 6
Mid_Body-2.step x 6
Mark-3.step x 6
Extruded-4.step
Extruded-5.step x 2
Extruded-6.step x 3
Extruded-7.step x 6
pins-8.step x 2
body-9.step x 2
top-10.step x 2
part number.step x 2
Mid_Body-12.step
Mark-13.step
Mid_Body-15.step
Mark-16.step
6182227104.step x 2
body-17.step
terminals.step
base.step
logo-18.step
Leadframe.step
Leadframe-19.step
Core.step
ShieldRing.step
Glue.step
1-20.step
2-21.step
3.step
Vishay logo.step
1x1_Pin_Header_2.54mm.step x 14
1x1_Pin_Header_2.54mm-22.step x 4
1-23.step
2-24.step
3-25.step
4.step
5.step
6.step
7.step
Molex.step
notch.step
Extruded-26.step x 2
Extruded-27.step x 2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

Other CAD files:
Enclosure/Enclosure1/14x1_Pin_Header_2.54mm.step.SLDASM
Enclosure/Enclosure1/04x1_Pin_Header_2.54mm.step.SLDASM
Enclosure/Enclosure1/TFT LCD 2.4 inch ILI9341-3.step.SLDPRT
Enclosure/Enclosure2/Enclosure/Button.SLDPRT
Enclosure/Enclosure2/STL/BackCover.STL
Enclosure/Enclosure2/STL/enclsoure2.STL
Enclosure/Enclosure1/1x1_Pin_Header_2.54mm.step.SLDPRT
Enclosure/Enclosure1/1x1_Pin_Header_2.54mm_1.step.SLDPRT
Enclosure/Enclosure1/Assem1.STL
Enclosure/Enclosure1/Bottom.SLDPRT
Enclosure/Enclosure1/CH340E.stp
Enclosure/Enclosure1/Component1.step.SLDPRT
Enclosure/Enclosure1/Component2.step.SLDPRT
Enclosure/Enclosure1/TFT LCD 2.4 inch ILI9341-0.step.SLDPRT
Enclosure/Enclosure1/TFT LCD 2.4 inch ILI9341-1.step.SLDPRT
Enclosure/Enclosure1/TFT LCD 2.4 inch ILI9341-2.step.SLDPRT
Enclosure/Enclosure1/TFT LCD 2.4 inch ILI9341-4.step.SLDPRT
Enclosure/Enclosure1/TFT LCD 2.4 inch ILI9341-5.step.SLDPRT
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

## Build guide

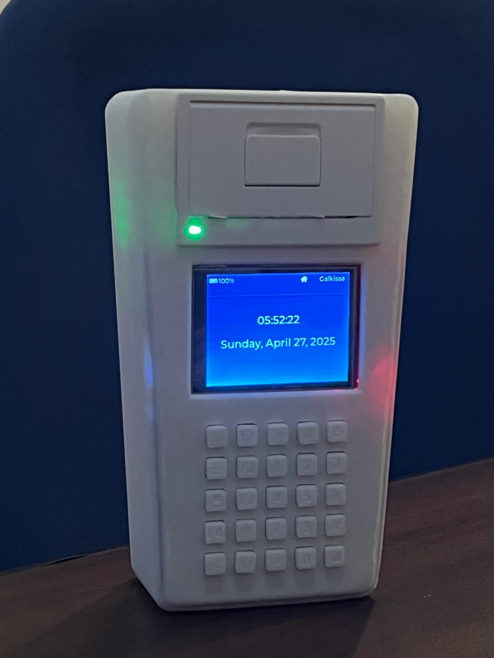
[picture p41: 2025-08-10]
Enclosure/Enclosure2/Enclosure/Printed2.jpg

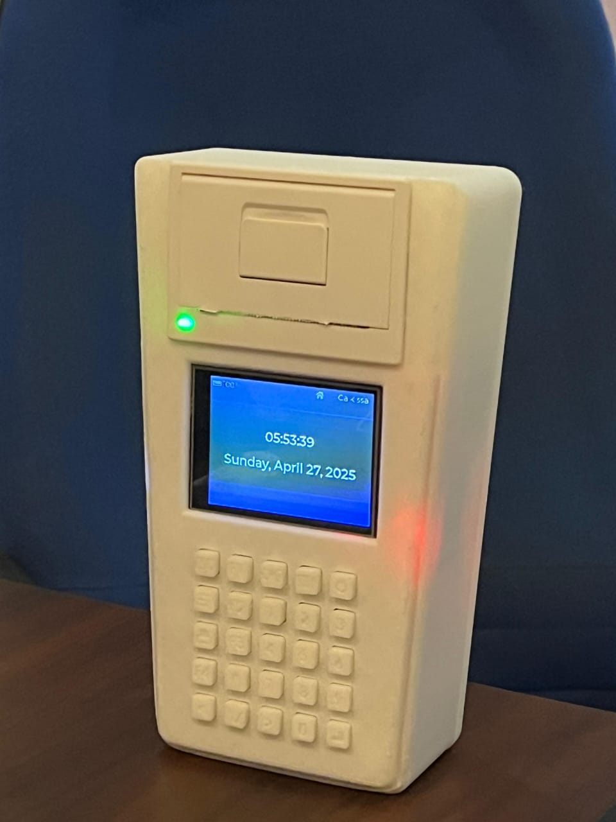
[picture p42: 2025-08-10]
Enclosure/Enclosure2/Enclosure/Printed.jpg

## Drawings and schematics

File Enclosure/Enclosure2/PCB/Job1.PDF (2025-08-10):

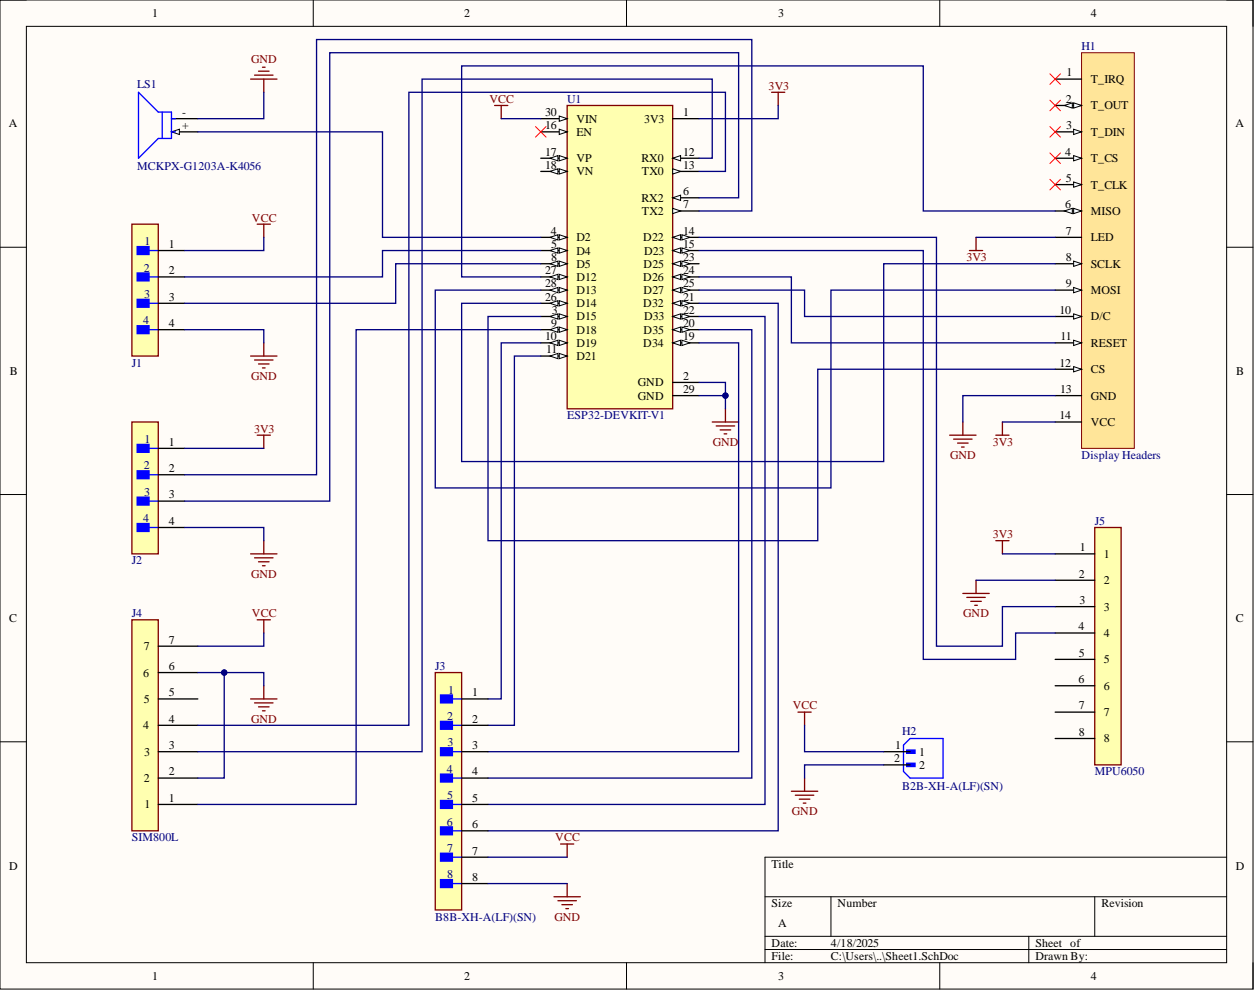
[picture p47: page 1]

VCC U 1

2 7 | | 2 4
2 8 | | 2 5
2 6 | | 2 1 | | | | 1 0
3 | D 1 4 D 3 2 D 1 5 D 3 3 | 2 2
9 | D 1 8 D 3 5 | 2 0 | | | | | | 1 1

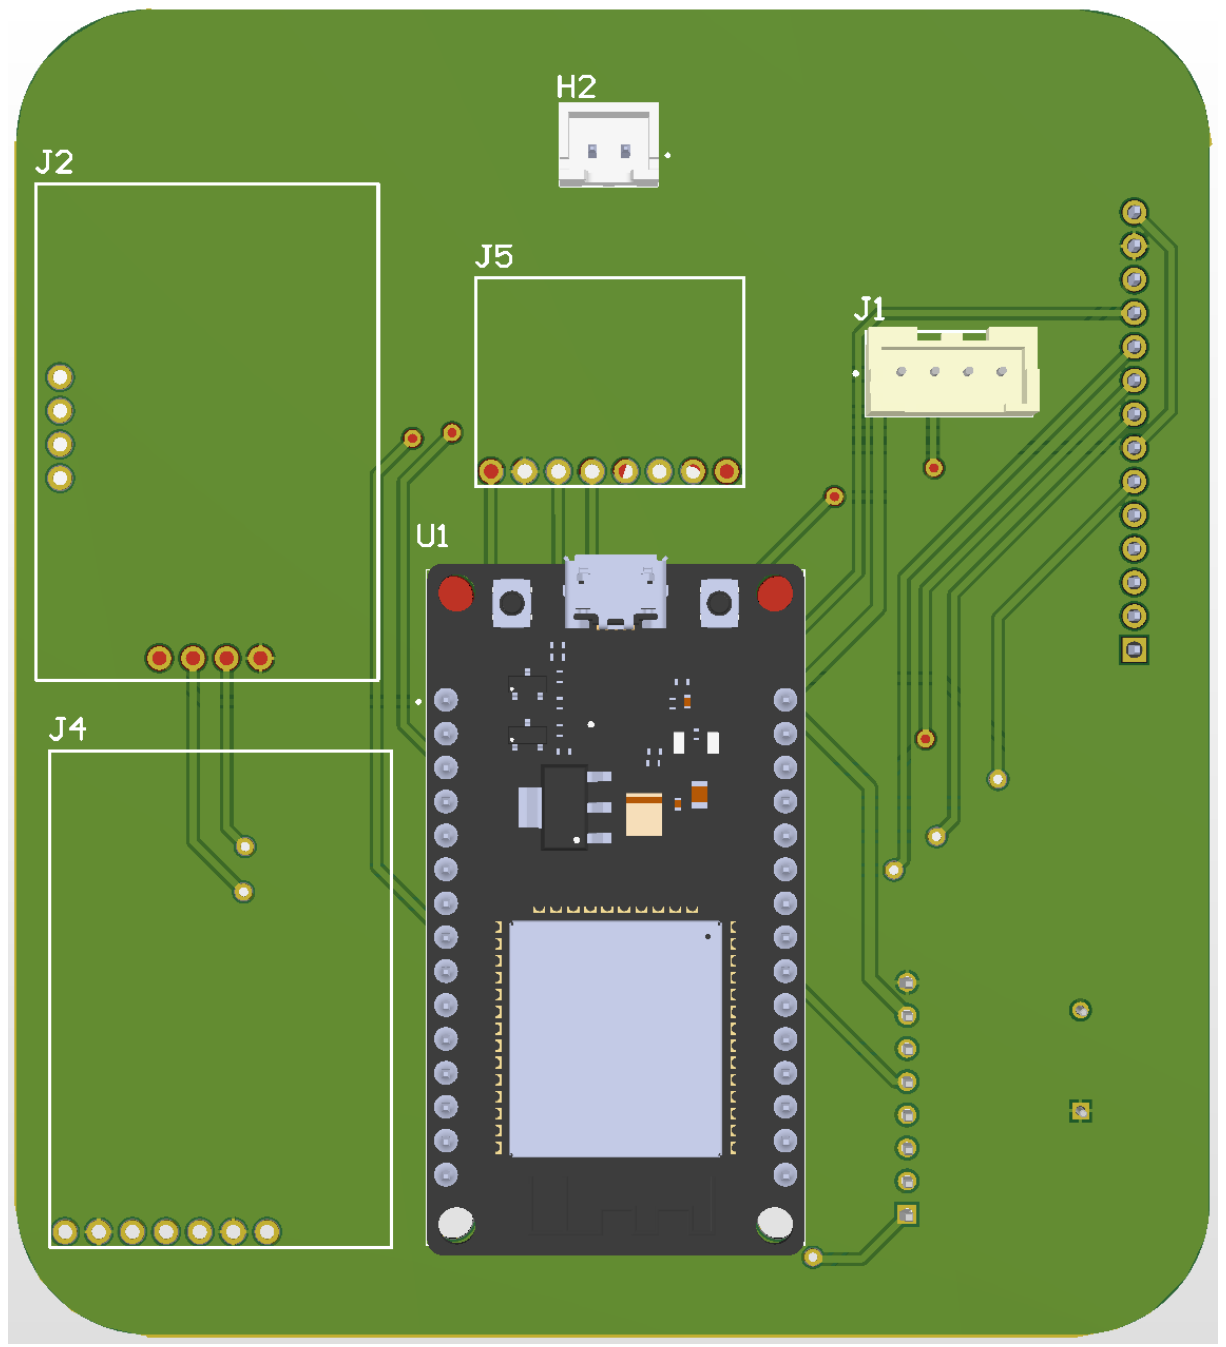
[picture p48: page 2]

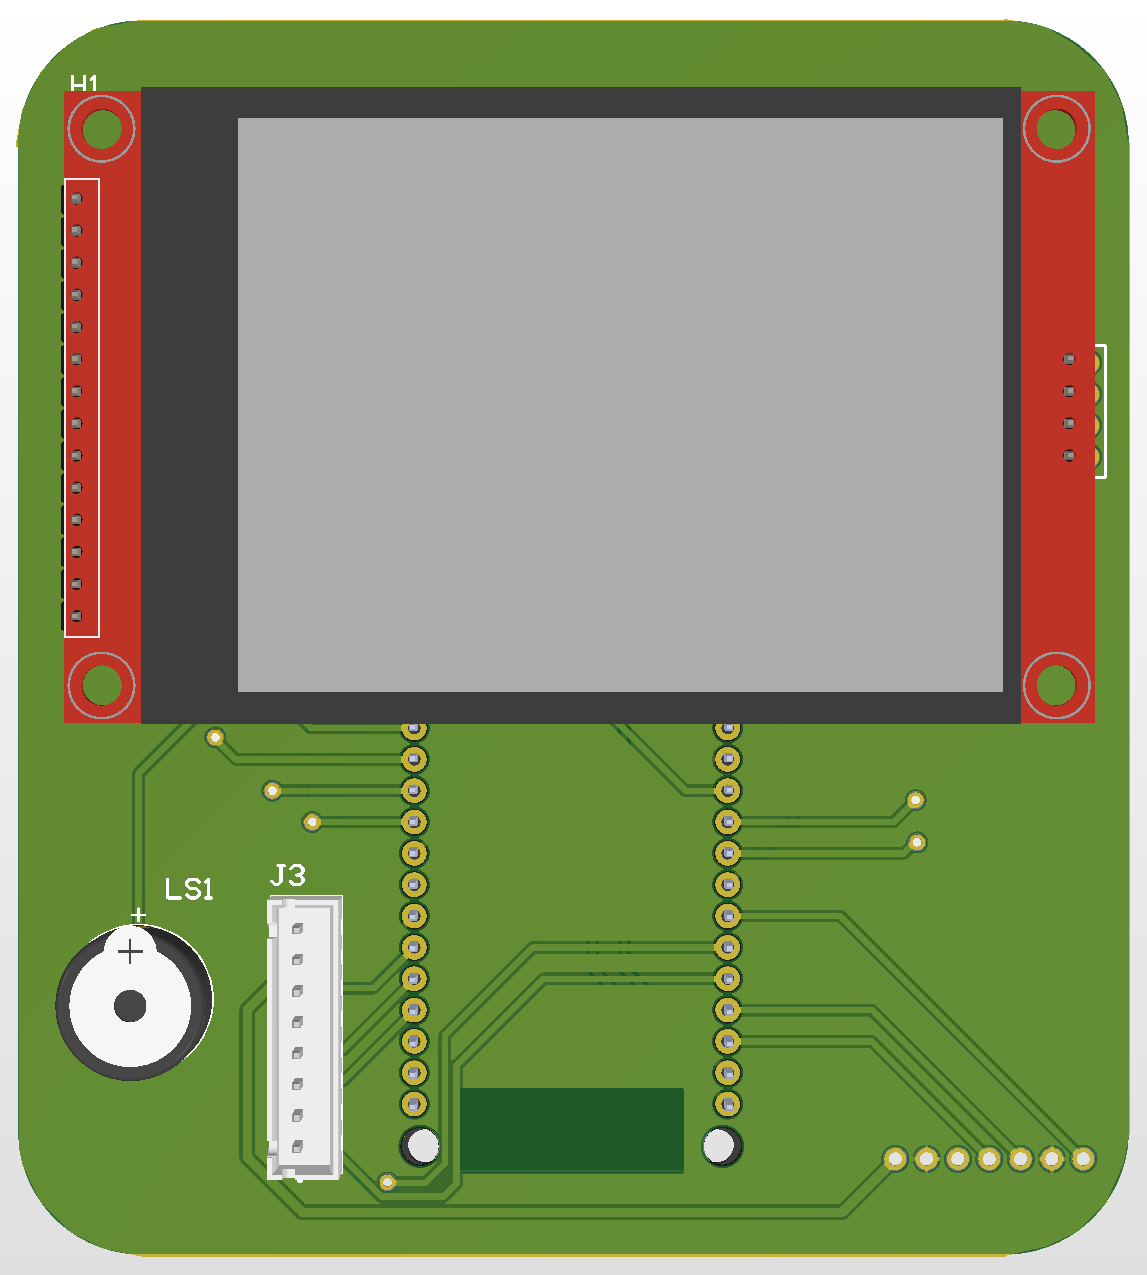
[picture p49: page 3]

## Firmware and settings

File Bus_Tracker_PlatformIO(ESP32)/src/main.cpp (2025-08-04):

#include <Arduino.h>
#include "Config.h"
#include "GPS.h"
#include "Key_Receiver.h"
#include "Bus_Ticket_Printer.h"
#include "Bus_Data.h"
#include "Bus_Display.h"
#include "Firebase_Connector.h"
#include "TimeManager.h"
#include "BusPreferences.h"
#include <Ticker.h>

// Define hardware serial ports
HardwareSerial gpsSerial(GPS_SERIAL_NUM);

// Create instances
GPS gps(&gpsSerial, GPS_RX_PIN, GPS_TX_PIN);
KeyReceiver keyReceiver;
BusTicketPrinter ticketPrinter;
BusDisplay display;
BusData bus;
FirebaseConnector firebase;
TimeManager timeManager;
BusPreferences preferences;


// Ticker objects for timers
Ticker gpsTicker;
Ticker displayTicker;
Ticker timeManagerTicker;

// Firebase timing using millis() instead of ticker
unsigned long previousFirebaseMillis = 0;

// Forward declarations
void updateGPS();
void updateTime();
void updateDisplay();
void sendToFirebase();

void setup() {
    // Initialize debug serial first at high baud rate
    Serial.begin(115200);
    Serial.println("\n\nESP32 Bus System Starting");

    pinMode(BUZZER_PIN, OUTPUT);
  
    tone(BUZZER_PIN, 2000);
    delay(1000);
    noTone(BUZZER_PIN);
  
    
    // Initialize bus preferences first to load saved values
    Serial.println("Initializing preferences...");
    if (preferences.begin()) {
        Serial.println("Preferences initialized successfully");
        // Load saved bus data
        if (preferences.loadBusData(bus)) {
            Serial.println("Loaded saved bus data from preferences");
        } else {
            Serial.println("No saved data found, using defaults");
            
            // Set default bus data if no saved data is found
            bus.registrationNumber = "ND-2314";
            bus.companyName = "Syntech Transit (Pvt) Ltd";
            bus.routeNumber = "0012";
            
            // Get a new reference number or start with default
            bus.referenceNumber = preferences.loadReferenceNumber();
            if (bus.referenceNumber.isEmpty()) {
                bus.referenceNumber = "10000000001";
                preferences.saveReferenceNumber(bus.referenceNumber);
            }
          
            bus.routeName = "Moratuwa - Nittambuwa";
            bus.fromHalt = "Katubedda";
            bus.toHalt = "Kadawatha";
            bus.isFullTicket = true;
            bus.ticketCount = 2;
            bus.unitPrice = 130.00;
          
            bus.driverPhone = "0703482664";
            bus.hotline = "0332297800";
            
            // Save these default values
            preferences.saveBusData(bus);
        }
    } else {
        Serial.println("Preferences initialization failed, using default values");
        
        // Default bus data when preferences fails
        bus.registrationNumber = "ND-2314";
        bus.companyName = "Syntech Transit (Pvt) Ltd";
        bus.routeNumber = "0012";
        bus.referenceNumber = "10000000001";
        
        bus.routeName = "Moratuwa - Nittambuwa";
        bus.fromHalt = "Katubedda";
        bus.toHalt = "Kadawatha";
        bus.isFullTicket = true;
        
        bus.ticketCount = 2;
        bus.unitPrice = 130.00;
        
        bus.driverPhone = "0703482664";
        bus.hotline = "0332297800";
    }
    
    // Set default date and time values that will be updated by TimeManager
    bus.date = "2025/03/21";
    bus.time = "00:00:00";
    
    Serial.println("Initializing display...");
    // Initialize components - start with display
    display.begin();
    delay(100); // Give the display time to initialize
    
    // Initialize time manager
    Serial.println("Initializing TimeManager...");
    if (timeManager.begin()) {
        Serial.println("TimeManager initialized successfully");
        // Update time immediately after successful initialization
        updateTime();
    } else {
        Serial.println("TimeManager initialization failed, using default time");
    }
    
    // Now initialize other components
    keyReceiver.begin();
    ticketPrinter.begin();
    
    // Initialize GPS serial
    Serial.println("Initializing GPS...");
    gpsSerial.begin(GPS_BAUD_RATE, SERIAL_8N1, GPS_RX_PIN, GPS_TX_PIN);
    
    // Initialize Firebase
    Serial.println("Initializing Firebase...");
    if (firebase.begin()) {
        Serial.println("Firebase connection successful");
    } else {
        Serial.println("Firebase connection failed, will retry later");
    }
    
    // Set up display data
    display.setLocation(bus.fromHalt.c_str());
    
    // Set up tickers
    Serial.println("Setting up tickers...");
    displayTicker.attach_ms(20, updateDisplay);  // 200 Hz refresh rate
    gpsTicker.attach(1.0, updateGPS);           // Update GPS every second
    timeManagerTicker.attach(1.0, updateTime);  // Update time every second
    
    // Initialize the previous millis for Firebase timing
    previousFirebaseMillis = millis();

    // Set ticket printer data using the method with BusData and TimeManager
    ticketPrinter.setTicketDataFromBus(bus, timeManager);

    Serial.println("Bus Ticketing System Ready");
}

void updateGPS() {
    gps.update();  // Parse new GPS data
    bus.latitude = gps.getLatitude();
    bus.longitude = gps.getLongitude();
    bus.speed = gps.getSpeedKmh();
}

void updateTime() {
    // Update time manager (checks if NTP sync is needed)
    timeManager.update();
    
    // Get time from TimeManager
    bus.time = timeManager.getTimeString();
    bus.date = timeManager.getDateString();
    
    // Update the time on the display
    display.setTime(
        timeManager.getHour(),
        timeManager.getMinute(),
        timeManager.getSecond()
    );
    
    // Update date on display only if it has changed
    static int lastDay = -1;
    int currentDay = timeManager.getDay();
    
    if (currentDay != lastDay) {
        display.setDate(
            timeManager.getYear(),
            timeManager.getMonth() - 1, // Display expects 0-based month
            timeManager.getDay(),
            timeManager.getDayOfWeek()
        );
        lastDay = currentDay;
    }
}

void updateDisplay() {
    display.update();
    display.setLocation(bus.getCurrentHaltName());
}

// Function to send data to Firebase
void sendToFirebase() {
    // Only send data if Firebase is initialized correctly
    if (firebase.isConnected()) {
        firebase.sendBusData(
            DEVICE_ID,
            bus.latitude,
            bus.longitude,
            bus.speed,
            bus.time,
            bus.getCurrentHaltName(),
            bus.passengerCount,
            bus.getDestinationHaltName()
        );
    } else {
        // Try to reconnect if not connected
        firebase.begin();
    }
}

void loop() {
    // Handle key inputs with the state machine
    keyReceiver.check_Key_and_Execute();
    
    // Check if it's time to send data to Firebase
    unsigned long currentMillis = millis();
    if (currentMillis - previousFirebaseMillis >= FIREBASE_INTERVAL) {
        previousFirebaseMillis = currentMillis;
        sendToFirebase();
    }
}

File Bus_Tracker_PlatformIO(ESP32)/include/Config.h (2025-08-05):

#ifndef CONFIG_H
#define CONFIG_H

// Device Identification
#define DEVICE_ID "bus10001"

// Serial Port Configurations
#define GPS_SERIAL_NUM 2    // UART2
#define PRINTER_SERIAL_NUM 1   // UART1
#define DEBUG_BAUD_RATE 115200
#define GPS_BAUD_RATE 9600
#define GPRS_BAUD_RATE 38400

// GPS Pin Configuration
#define GPS_RX_PIN 16  // Using numeric value instead of GPIO_NUM_16
#define GPS_TX_PIN 17  // Using numeric value instead of GPIO_NUM_17

// GPRS Pin Configuration
#define PRINTER_RX_PIN 5  // Using numeric value instead of GPIO_NUM_5
#define PRINTER_TX_PIN 4  // Using numeric value instead of GPIO_NUM_4

// GPRS Network Configuration
#define GPRS_APN "internet"
#define DEFAULT_SMS_NUMBER "+94712345678"

// TCP Server Configuration
#define TCP_SERVER "your-server.com"
#define TCP_PORT 8080

// Timing Configuration
#define TCP_UPDATE_INTERVAL 60000    // 1 minute in milliseconds
#define GPS_UPDATE_INTERVAL 1000     // 1 second in milliseconds

// Buffer Sizes
#define TCP_MESSAGE_BUFFER_SIZE 256  // Use the larger buffer size

// Screen settings
#define SCREEN_WIDTH 320
#define SCREEN_HEIGHT 240

// WiFi settings
#define WIFI_SSID "Chiki Chiki Bamba"
#define WIFI_PASSWORD "DiscreteFourierTransform"

// Firebase settings

const unsigned long FIREBASE_INTERVAL = 10000; // milliseconds

const int BUZZER_PIN = 2;

#endif // CONFIG_H

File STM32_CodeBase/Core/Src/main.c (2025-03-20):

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
/* Includes ------------------------------------------------------------------*/
#include "main.h"

/* USER CODE BEGIN Includes */
#include "lvgl.h"
#include "LCDController.h"
/* USER CODE END Includes */

SPI_HandleTypeDef hspi1;
DMA_HandleTypeDef hdma_spi1_tx;

UART_HandleTypeDef huart2;

/* USER CODE BEGIN PV */
uint8_t tx_buffer[50] = "Jetson Nano Developer Kit ----- LKR 75000";
/* USER CODE END PV */

void SystemClock_Config(void);
static void MX_GPIO_Init(void);
static void MX_DMA_Init(void);
static void MX_SPI1_Init(void);
static void MX_USART2_UART_Init(void);
/**
  * @brief  The application entry point.
  * @retval int
  */
int main(void)
{

  /* MCU Configuration--------------------------------------------------------*/

  /* Reset of all peripherals, Initializes the Flash interface and the Systick. */
  HAL_Init();

  /* Configure the system clock */
  SystemClock_Config();

  /* Initialize all configured peripherals */
  MX_GPIO_Init();
  MX_DMA_Init();
  MX_SPI1_Init();
  MX_USART2_UART_Init();
  /* USER CODE BEGIN 2 */
	lv_init();
	lv_port_disp_init();


//	lv_obj_set_style_bg_color(lv_scr_act(), lv_color_hex(0x003a57),
//			LV_PART_MAIN);
//	lv_obj_set_style_text_color(lv_scr_act(), lv_color_hex(0xffffff),
//			LV_PART_MAIN);
//
//	/* Create a spinner */
//	lv_obj_t *spinner = lv_spinner_create(lv_scr_act(), 1000, 60);
//	lv_obj_set_size(spinner, 64, 64);
//	lv_obj_align(spinner, LV_ALIGN_BOTTOM_MID, 0, 0);
	lv_demo_benchmark();
  /* USER CODE END 2 */

  /* Infinite loop */
  /* USER CODE BEGIN WHILE */
	bool firstTime = true;

	while (1) {
	    if (firstTime) {
	        HAL_Delay(1000);
	        HAL_UART_Transmit(&huart2, tx_buffer, 50, 10);
	        firstTime = false;
	    }
    /* USER CODE BEGIN 3 */
	}
  /* USER CODE END 3 */
}

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


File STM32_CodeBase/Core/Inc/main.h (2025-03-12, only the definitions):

#define CS_Pin GPIO_PIN_4
#define CS_GPIO_Port GPIOA
#define D_C_Pin GPIO_PIN_8
#define D_C_GPIO_Port GPIOA
#define RESET_Pin GPIO_PIN_9
#define RESET_GPIO_Port GPIOA

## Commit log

2025-03-20 added uart for printer. but not working
    [Syntrack.ioc, main.c]
2025-08-04 added platform io files
    [huge_app.csv]
2025-08-08 added PCBs
    [Buzzer.SchDoc, Display.SchDoc, GPRS.SchDoc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]
2025-08-10 added enclosure designs
    [04x1_Pin_Header_2.54mm.step.SLDASM, 14x1_Pin_Header_2.54mm.step.SLDASM, 1x1_Pin_Header_2.54mm.step.SLDPRT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]

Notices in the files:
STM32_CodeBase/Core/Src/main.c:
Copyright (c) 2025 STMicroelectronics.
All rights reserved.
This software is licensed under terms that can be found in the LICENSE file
